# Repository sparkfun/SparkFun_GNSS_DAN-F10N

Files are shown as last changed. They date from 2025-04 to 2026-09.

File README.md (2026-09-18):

SparkFun Dualband L1/L5 GNSS Breakout - DAN-F10N
========================================

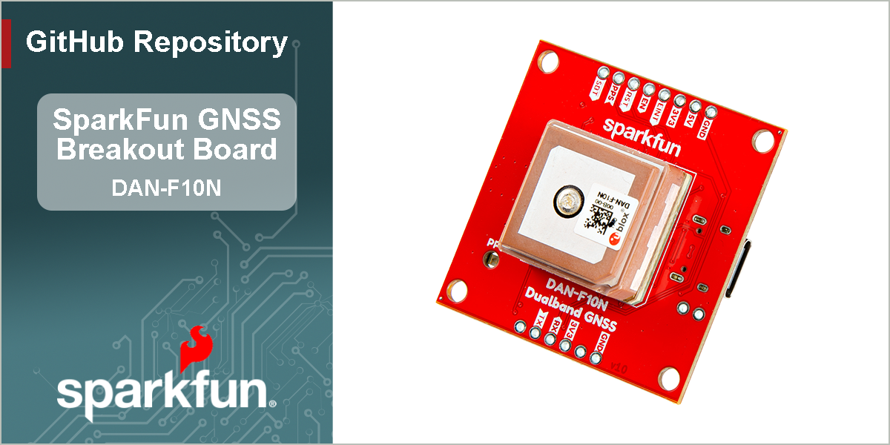
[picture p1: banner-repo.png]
SparkFun Dualband L1/L5 GNSS Breakout - DAN-F10N


[*SparkFun Dualband L1/L5 GNSS Breakout - DAN-F10N (GPS-28435)*](https://www.sparkfun.com/sparkfun-dualband-l1-l5-gnss-breakout-dan-f10n.html)

The SparkFun DAN-F10N Dualband GNSS Breakout is built around the powerful u-blox F10 engine, offering simultaneous reception of L1 and L5 frequency bands. This board leverages u-blox's advanced multipath mitigation technology to isolate the strongest signals, delivering reliable, meter-level position accuracy even in dense urban canyons. To ensure signal integrity, the module incorporates a robust SAW-LNA-SAW RF front-end with an additional notch filter (LTE B13), providing excellent rejection of interference from nearby cellular modems.

The SparkFun Dualband L1/L5 GNSS Breakout - DAN-F10N features u-blox's dual-band GNSS technology for the L1/L5 frequency bands. Their proprietary dual-band multipath mitigation technology enables the u-blox F10 GNSS engine to isolate the best signals from the L1 and L5 bands; delivering a solid meter-level position accuracy in challenging urban environments. Additionally, the DAN-F10N module's robust SAW-LNA-SAW RF architecture with an additional notch filter (LTE B13) on the L1 RF path ensures the best possible out-of-band interference mitigation from nearby cellular modems.

The DAN-F10N GNSS module on this board comes with a 20 x 20 x 8 mm, integrated, Right Hand Circular Polarized (RHCP), L1/L5 dual-band patch antenna that offers the best compromise between size and performance. The patch antenna's wide beamwidth provides flexibility in the device's orientation; while alternatively, the module also has an antenna switch function to give users the option to utilize an external dual-band antenna, further increasing its utility.

The DAN-F10N module is supported by the u-blox u-center 2 GNSS software for real-time performance analysis, receiver configuration, and data logging. The AssistNow Online, Offline, and Autonomous A-GNSS services can also be used with the module for faster satellite acquisition. Users can also interface with the GNSS module using NMEA 4.11 and UBX binary protocols.

> [!NOTE]
> The GPS `L5` signals are currently, considered as *"pre-operational"* and not utilized by default in navigation solutions. However, it is possible override the receiver's configuration to evaluate the GPS `L5` signals. Please refer to the integration manual for more details.
> 
> This is an operational limitation of the satellite/space segment and not an issue of the u-blox product.

Documentation
-------------

- **[Hookup Guide (mkdocs)](http://docs.sparkfun.com/SparkFun_GNSS_DAN-F10N/)** - A hookup guide for the SparkFun DAN-F10N Dualband L1/L5 GNSS breakout board hosted by GitHub pages.<br>
   
- [SparkFun u-blox GNSS v3 Arduino Library](https://github.com/sparkfun/SparkFun_u-blox_GNSS_v3) - An Arduino library for the u-blox GNSS module

Repository Contents
-------------------

- **[/docs](/docs/)** - Online documentation files
  - [/assets](/docs/assets/) - Assets files
    - [/3d_model](/docs/assets/3d_model/) - 3D models for the board
    - [/board_files](/docs/assets/board_files/) - Design files for the board
      - [KiCad Design Files](/docs/assets/board_files/kicad_files.zip) (.zip)
      - [Schematic](/docs/assets/board_files/schematic.pdf) (.pdf)
      - [Dimensions](/docs/assets/board_files/dimensions.pdf) (.pdf)
    - [/component_documentation](/docs/assets/component_documentation/) - Datasheets for hardware components
    - [/img/hookup_guide](/docs/assets/img/hookup_guide/) - Images for hookup guide documentation - Hookup guide images for the board
    - /Hardware - Hardware design files (.brd, .sch)
      - /Production - Production files

Product Variants
----------------

- [GPS-28435](https://www.sparkfun.com/sparkfun-dualband-l1-l5-gnss-breakout-dan-f10n.html) - Breakout Board
- [GPS-29061](https://www.sparkfun.com/sparkpnt-gnss-flex-module-dan-f10n.html) - SparkPNT GNSS Flex Module
- [GPS-29491](https://www.sparkfun.com/sparkfun-gnss-flex-phat-dan-f10n.html) - SparkFun GNSS Flex pHAT *(kit)*

Version History
---------------

- [v10](https://github.com/sparkfun/SparkFun_GNSS_DAN-F10N/releases/tag/v10) - Initial Release

License Information
-------------------

This product is ***open source***!

Please review the [`LICENSE.md`](./LICENSE.md) file for license information.

If you have any questions or concerns about licensing, please contact technical support on our [SparkFun forums](https://community.sparkfun.com/).

Distributed as-is; no warranty is given.

- Your friends at SparkFun.

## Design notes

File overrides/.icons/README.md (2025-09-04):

.icons directory
====================
This folder should contain branding logos for the product documentation

## General Images
- `sfe.svg` - SparkFun flame logo
- `kicad-primary.svg` - Full KiCad logo

## Directory
- `logo` - Other available logos

## SVG Optimizer
- [Remove meta data from svg](https://jakearchibald.github.io/svgomg/)

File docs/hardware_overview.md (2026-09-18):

## :material-folder-cog: Design Files

<!-- Import the component -->
<script type="module" src="https://ajax.googleapis.com/ajax/libs/model-viewer/3.5.0/model-viewer.min.js"></script>

<div class="grid cards desc" markdown>

-   :kicad-primary:{ .enlarge-logo } Design Files

	---

	- :fontawesome-solid-file-pdf: [Schematic](./assets/board_files/schematic.pdf)
	- :material-folder-zip: [KiCad Files](./assets/board_files/kicad_files.zip)
	- :material-rotate-3d: [STEP File](./assets/3d_model/cad_model.step)
	- :fontawesome-solid-file-pdf: [Board Dimensions](./assets/board_files/dimensions.pdf):
		- 2.50" x 2.00" (635mm x 508mm)

-   <!-- Boxes in tabs -->

	=== "3D Model"
		<article style="text-align: center;" markdown>
		<model-viewer src="../assets/3d_model/web_model.glb" camera-controls poster="../assets/3d_model/poster.png" tone-mapping="neutral" shadow-intensity="2" shadow-softness="0.2" camera-orbit="0deg 75deg 0.103m" field-of-view="25.11deg" style="width: 100%; height: 450px;">
		</model-viewer>

		[Download the `*.step` File](./assets/3d_model/cad_model.step "Click download"){ .md-button .md-button--primary width="250px" }

		</article>

		???+ tip "Manipulate 3D Model"
			<article style="text-align: center;" markdown>

			| Controls       | Mouse                    | Touchscreen    |
			| :------------- | :----------------------: | :------------: |
			| Zoom           | Scroll Wheel             | 2-Finger Pinch |
			| Rotate         | ++"Left-Click"++ & Drag  | 1-Finger Drag  |
			| Move/Translate | ++"Right-Click"++ & Drag | 2-Finger Drag  |

			</article>

	=== "Dimensions"
		<article style="text-align: center;" markdown>
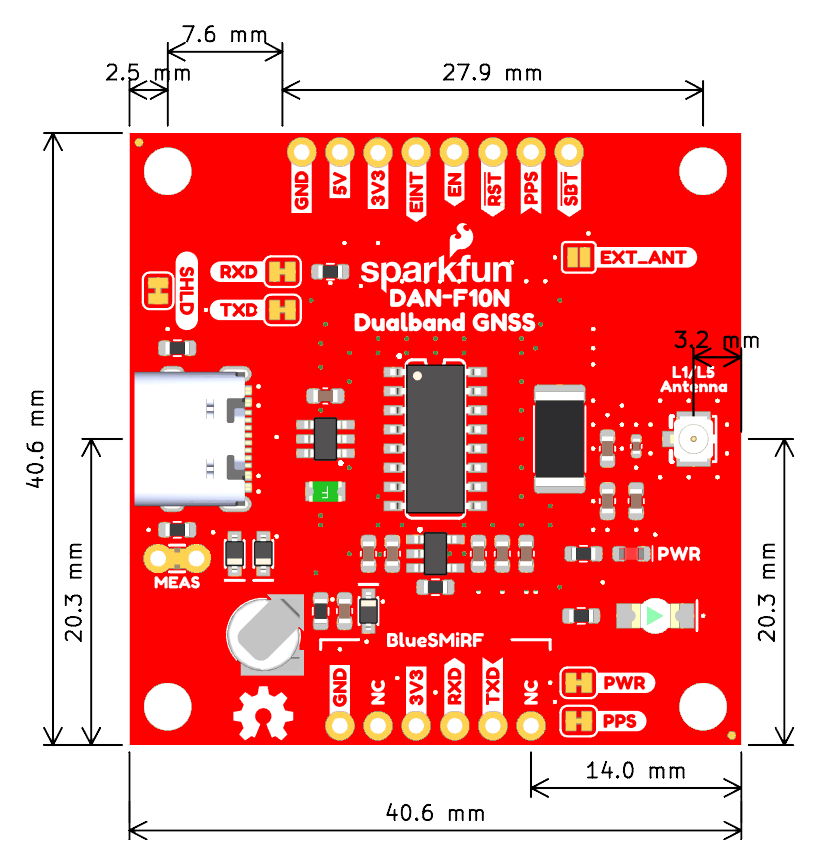
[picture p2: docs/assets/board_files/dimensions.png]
Board Dimensions
		
		<figcaption markdown>Dimensions of the DAN-F10N GNSS breakout board.</figcaption>
		</article>

		???+ tip "Need more measurements?"
			For more information about the board's dimensions, users can download the [KiCad files](./assets/board_files/kicad_files.zip) for this board. These files can be opened in KiCad and additional measurements can be made with the measuring tool.

			!!! info ":octicons-download-16:{ .heart } KiCad - Free Download!"
				KiCad is free, open-source [CAD]("computer-aided design") program for electronics. Click on the button below to download their software. *(\*Users can find out more information about KiCad from their [website](https://www.kicad.org/).)*

				<article style="text-align: center;" markdown>
				[Download :kicad-primary:{ .enlarge-logo }](https://www.kicad.org/download/ "Go to downloads page"){ .md-button .md-button--primary width="250px" }
				</article>

			???+ info ":straight_ruler: Measuring Tool"
				This video demonstrates how to utilize the dimensions tool in KiCad, to include additional measurements:

				<article class="video-500px" style="text-align: center; margin: auto;" markdown>
				<iframe src="https://www.youtube.com/embed/-eXuD8pkCYw" title="KiCad Dimension Tool" frameborder="0" allow="accelerometer; autoplay; clipboard-write; encrypted-media; gyroscope; picture-in-picture" allowfullscreen></iframe>
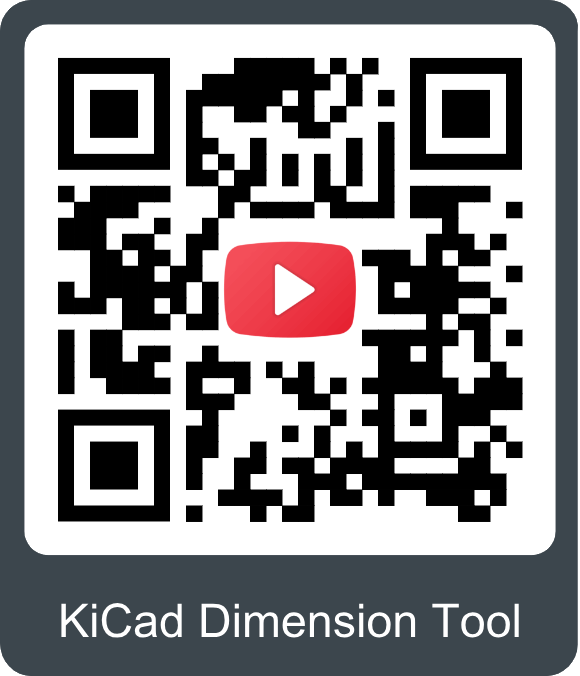
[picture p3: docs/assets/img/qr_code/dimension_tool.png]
QR code to play video
				
				</article>

</div>

## Board Layout
The SparkFun Dualband L1/L5 GNSS Breakout - DAN-F10N features the following:

<div class="grid" markdown>

<div markdown>

<figure markdown>
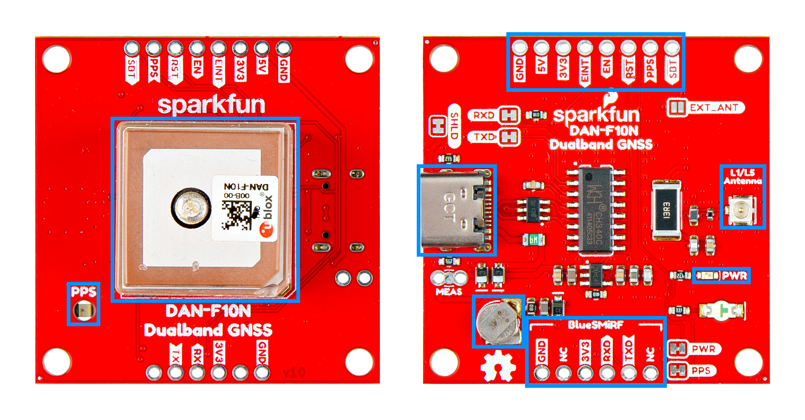
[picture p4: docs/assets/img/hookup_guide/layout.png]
Layout

<figcaption markdown>Layout of the major components on the breakout board.</figcaption>
</figure>

</div>

<div markdown>

1. **USB-C Connector**
:   The primary inteface for powering and interacting with the board
1. **DAN-F10N GNSS Module**
:   The u-blox DAN-F10N GNSS module
1. **Headers**
:   Exposes pins to power the board and breaks out the pins of the DAN-F10N GNSS module
1. **Status LEDs**
:   LED status indicators for the DAN-F10N GNSS module
1. **`L1/L5 Antenna` U.FL Connector**
:   An optional input for an external GNSS antenna
1. **Backup Battery**
:   Backup power to maintain ephemeris data on the DAN-F10N GNSS module for warm starts

</div>

</div>

## Power
The simplest method to power the board is through the USB-C connector. However, the DAN-F10N Dualband L1/L5 GNSS breakout board only requires **3.3V**, which can be supplied though the [PTH](https://en.wikipedia.org/wiki/Through-hole_technology "Plated Through Holes") pins.

<figure markdown>
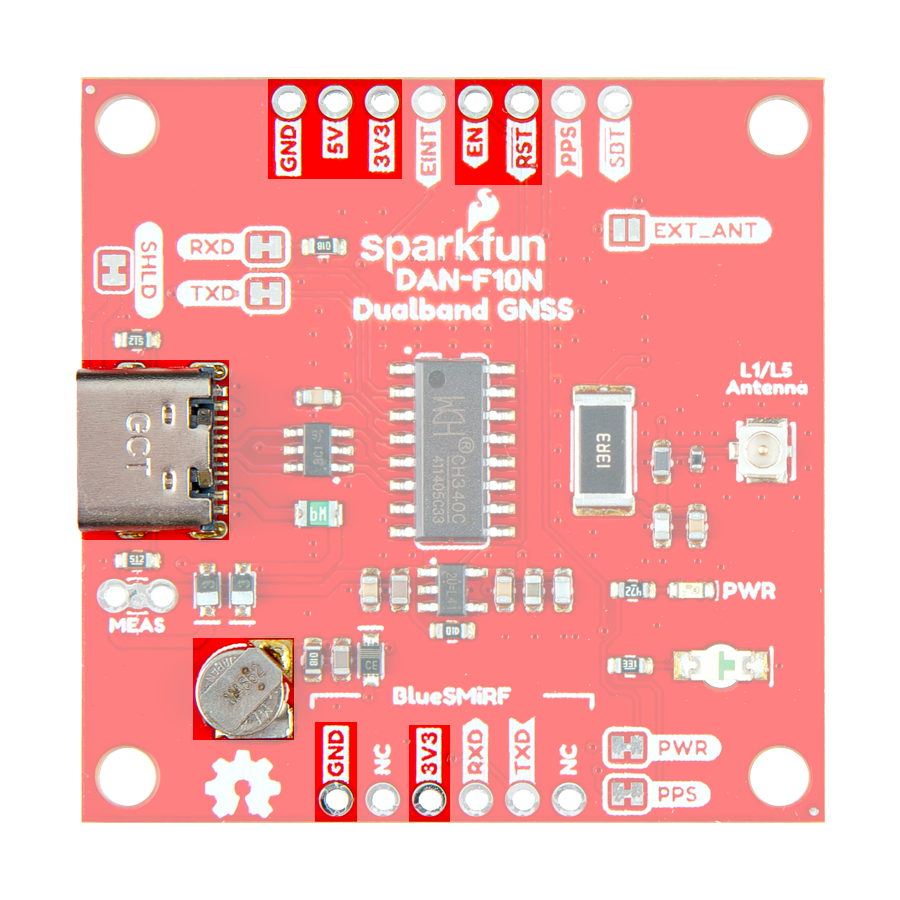
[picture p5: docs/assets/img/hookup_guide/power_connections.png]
Power connections

<figcaption markdown>DAN-F10N Dualband L1/L5 GNSS breakout board's power connections.</figcaption>
</figure>

Below, is a general summary of the power circuitry on the board; most are broken out as [PTH](https://en.wikipedia.org/wiki/Through-hole_technology "Plated Through Holes") pins:

<div class="annotate" markdown>

- **`5V`** - The voltage from the USB-C connector, usually **5V**.
	- Input Voltage Range: 1.2 - 5.5V (1)
	- Power source for the entire board
		- Powers the 3.3V voltage regulator (RT9080), which can source up to 600mA
		- When enabled, it can also power the [BlueSMiRF header](#bluesmirf-header)
- **`3V3`** - Provides a regulated 3.3V from the [RT9080](./assets/component_documentation/RT9080.pdf), using the power supplied from the `5V` pin or USB-C connector.
	- Used to power the DAN-F10N module, power LED, and backup battery
	- Controlled by the `EN` pin, which is enabled by default
- **`EN`** - Controls the 3.3V voltage regulator [RT9080](./assets/component_documentation/RT9080.pdf), enabling the voltage output *(active `HIGH`)*
- **`RST`** - Used to reset the DAN-F10N GNSS module
	- Connected to the [`RESET_N` pin](#pio-pins) of the DAN-F10N module, an input-only pin with an internal pull-up resistor (2)
	- Driving the pin `LOW` for at least 1ms triggers a cold-start reset, clearing the `BBR` content *(receiver configuration, real-time clock (RTC), and GNSS orbit data)*
- **`GND`** - The common ground or the 0V reference for the voltage supplies.
- **Backup Battery** - Provides backup power to the DAN-F10N GNSS module to maintain ephemeris data for warm starts

</div>

1. While the [RT9080](./assets/component_documentation/RT9080.pdf) LDO regulator has an input voltage range of 1.2 - 5.5V, a minimum supply voltage of **3.5V** is recommended for a 3.3V output.

1. No capacitors should be placed between `RESET_N` to GND, otherwise it could trigger a reset on every startup.

!!! tip "JST Connector"
	The `3V3` pin of the [BlueSMiRF header](#bluesmirf-header) is designed to operate as a voltage output. However, an input voltage can be supplied through the pin, but users should be mindful of any voltage contention issues.

!!! info
	For more details, users can reference the [schematic](./assets/board_files/schematic.pdf) and the datasheets of the individual components on the board.

### Power Modes
The DAN-F10N GNSS module supports three different operation modes:

- ***Continuous Mode***

:   In this mode, the module uses dedicated signal processing engines optimized for signal acquisition and tracking.

	- The acquisition engine actively searches and acquires signals, during cold starts or when insufficient signals are available during navigation.
	- The tracking engine continuously tracks signals, downloads all the almanac data, and acquires new signals as they become available during navigation.
	
	The tracking engine consumes less power than the acquisition engine. Therefore, the module's current consumption is lower when a valid position is obtained quickly after startup, the entire almanac has been downloaded, and the ephemeris for available satellites are valid.

- *Backup Modes*

:   The DAN-F10N module supports two backup modes. The backup modes are inactive states with reduced power consumption, where the receiver maintains time, information, and navigation data to speed up signal acquisitions upon restart.

	- **Hardware backup mode**

	:   The hardware backup mode requires `V_BCKP` power to be supplied. It allows the module to enter a backup state and maintain the backup domain (`BBR` and `RTC`), after the main power has been switched off.

	- **Software standby mode**

	:   Software standby mode is entered using the `UBX-RXM-PMREQ` message. This mode will clear the RAM memory; to maintain the receiver configuration, it should be stored on `BBR` or flash layers. The software standby mode can be set for a specific duration, or until the receiver is woken up by a signal from the UART `RX` and/or `EXTINT` pins, as defined in `UBX-RXM-PMREQ` message. A system reset with the `RESET_N` signal also terminates the software standby mode, clears the `BBR` content and restarts the receiver.

### Power Consumption
The power consumption of the DAN-F10N module depends on the GNSS signals enabled and if the module is acquiring or tacking those signals. The table below, lists the average current consumption with a supply voltage of 3.3V.

<div class="grid cards" markdown>

<article style="text-align: center;" markdown>

| GNSS Signals | Acquisition | Tracking |
| :--- | :---: | :---: |
| GPS+GAL+BDS  | 26mA | 21mA |
| GPS+BDS | 26mA | 20mA |
| GPS+GAL | 22mA | 19mA |
| GPS+NavIC | 21mA | 18mA |
| GPS | 20mA | 18mA |
| BDS | 24mA | 19mA |

</article>

<div markdown>

!!! tip
	At startup, the inrush current can reach up to 100 mA at startup. Make sure the primary power source can sustain the required current consumption.

!!! info "Backup Modes"
	The current consumption for the backup modes:

	- Hardware backup Mode: 31µA
	- Software standby Mode: 49µA

!!! info
	For more information, please refer to the [DAN-F10N Datasheet](./assets/component_documentation/DAN-F10N_DataSheet_UBXDOC-963802114-13074.pdf).

</div>

</div>

## DAN-F10N GNSS Receiver
The centerpiece of the DAN-F10N Dualband L1/L5 GNSS breakout board, is the [DAN-F10N module](./assets/component_documentation/DAN-F10N_DataSheet_UBXDOC-963802114-13074.pdf) from [u-blox](https://www.u-blox.com/en). Their proprietary dual-band multipath mitigation technology enables the u-blox F10 GNSS engine to isolate the best signals from the L1 and L5 bands; delivering a solid meter-level position accuracy in challenging urban environments. Additionally, the DAN-F10N module's robust SAW-LNA-SAW RF architecture with an additional notch filter on the L1 RF path ensures the best possible out-of-band interference mitigation from nearby cellular modems.

The DAN-F10N GNSS module comes with a 20 x 20 x 8 mm, integrated, Right Hand Circular Polarized (RHCP), L1/L5 dual-band patch antenna that offers the best compromise between size and performance. The patch antenna's wide beamwidth provides flexibility in the device's orientation; while alternatively, the module also has an antenna switch function to give users the option to utilize an external dual-band antenna, further increasing its utility.

<div class="grid cards" markdown>

<div markdown>

<article class="video-500px" style="text-align: center; margin: auto;" markdown>
<iframe src="https://www.youtube.com/embed/7_Pxe2rVFIQ" title="u-blox F10 GNSS platform for meter-level accuracy in urban environments" frameborder="0" allow="accelerometer; autoplay; clipboard-write; encrypted-media; gyroscope; picture-in-picture" allowfullscreen></iframe>
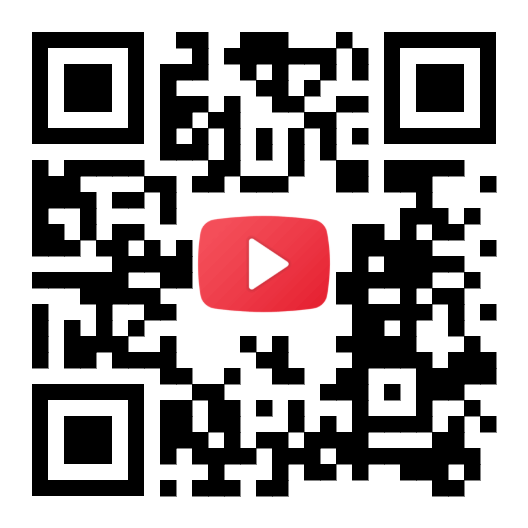
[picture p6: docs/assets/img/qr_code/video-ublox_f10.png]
QR code

</article>

</div>

-   <figure markdown>
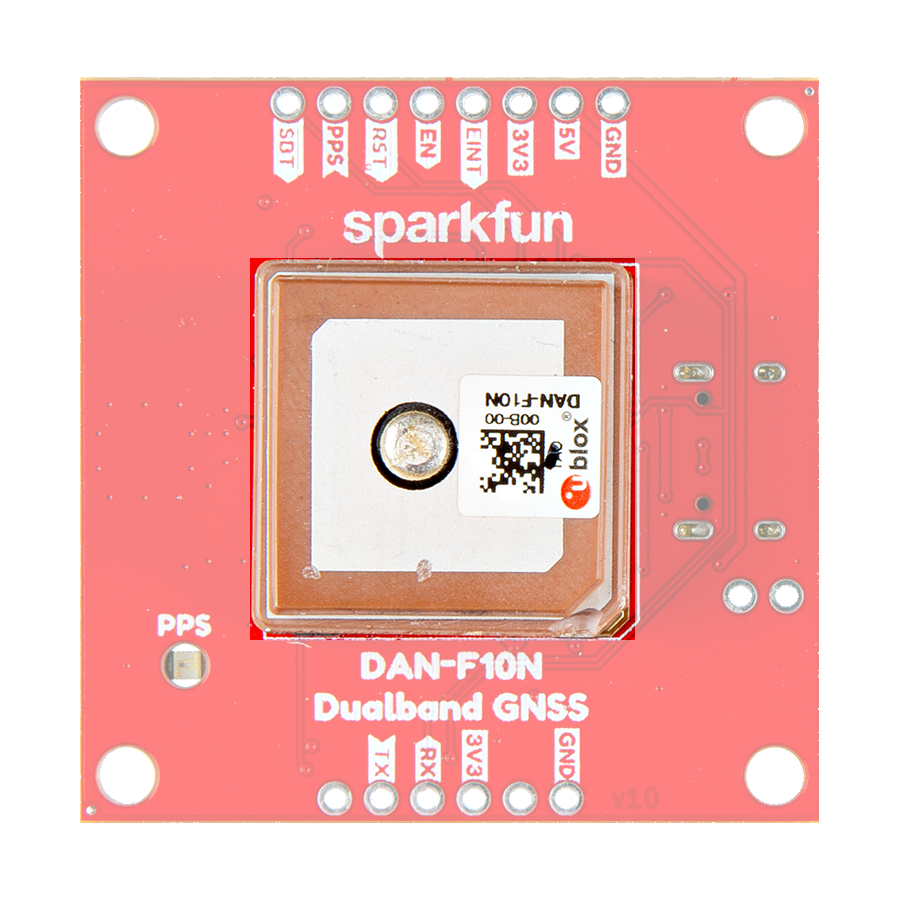
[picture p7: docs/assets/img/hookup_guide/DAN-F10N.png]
DAN-F10N module
	
	<figcaption markdown>The DAN-F10N module on the breakout board.</figcaption>
	</figure>

</div>

<div class="grid" markdown>

<div markdown>

**Features:**

- Operating Voltage: **2.7 - 3.6V**
- Operating Temperature: -40 - 85&deg;C
- GNSS Support
	- GPS: L1 C/A, L5
	- QZSS: L1C/A, L1S, L1Sb, L5
	- GAL: E1B/C, E5a
	- BDS: B1C, B2a
	- NavIC: L5
	- SBAS: L1C/A
	- BDSBAS: B1C
- Sensitivity
	- Tracking & Nav: –164dBm
	- Reacquisition: –156dBm
	- Cold start: –145dBm
	- Hot start: –156dBm

</div>

<div markdown>

<br>

- Update Rate: Up to 10Hz
- Time to Fix
	- Cold Start: < 28s
	- Aided Start: < 2s
	- Hot Start: 2s
- Position Accuracy
	- 1.0 m (with SBAS)
	- 1.5 m (without SBAS)
- Interfaces
	- 1x Serial interface
		- Raw data output: Code phase data
		- Protocols: NMEA 4.11, UBX binary
	- 2x Digital I/O
		- Timepulse Configurable: 0.25 - 10MHz
		- `EXTINT` input for Wakeup

</div>

</div>

### Frequency Bands
The DAN-F10N GNSS module is a dual-band, multi-constellation GNSS receiver. Below, are the frequency bands provided by all the global navigation satellite systems and the ones supported by the DAN-F10N module.

<div class="grid cards desc" markdown>

<article style="text-align: center;" markdown>

| Constellation | Frequency Bands |
| :---: | :--- |
| GPS | L1 C/A, L5 |
| QZSS | L1C/A, L1S, L1Sb, L5 |
| GAL | E1B/C, E5a |
| BDS | B1C, B2a |
| NavIC | L5 |
| SBAS | L1C/A |
| BDSBAS | B1C |

*The frequency bands supported by the DAN-F10N GNSS receiver.*
</article>

<div markdown>

<figure markdown>
GNSS frequency bands (https://www.tallysman.com/app/uploads/2021/07/Tallysman-GNSS-Frequencies-v8.0_Chart-1-1024x425.png "Click to enlarge")
<figcaption markdown>Frequency bands of the global navigation satellite systems. (Source: [Tallysman](https://www.tallysman.com/gnss-constellations-radio-frequencies-and-signals/))</figcaption>
</figure>

</div>

</div>

??? info "What are Frequency Bands?"
	A [frequency band](https://en.wikipedia.org/wiki/Frequency_band) is a section of the [electromagnetic spectrum](https://en.wikipedia.org/wiki/Electromagnetic_spectrum), usually denoted by the range of its upper and lower limits. In the [radio spectrum](https://en.wikipedia.org/wiki/Radio_spectrum), these frequency bands are usually regulated by region, often through a government entity. This regulation prevents the interference of RF communication; and often includes major penalties for any interference with critical infrastructure systems and emergency services.

	<figure markdown>
	GNSS frequency bands (https://gssc.esa.int/navipedia/images/c/cf/GNSS_All_Signals.png "Click to enlarge")
	<figcaption markdown>Frequency bands of the global navigation satellite systems. (Source: [ESA](https://gssc.esa.int/navipedia/index.php?title=File:GNSS_All_Signals.png "European Space Agency"))</figcaption>
	</figure>

	However, if the various GNSS constellations share similar frequency bands, then how do they avoid interfering with one another? Without going too far into detail, the image above illustrates the frequency bands of each system with a few characteristics specific to their signals. Wit these characteristics in mind, along with other factors, the chart can help users to visualize how multiple GNSS constellations might co-exist with each other.

	For more information, users may find these articles of interest:

	- [GNSS signal](https://gssc.esa.int/navipedia/index.php/GNSS_signal)
	- [GPS Signal Plan](https://gssc.esa.int/navipedia/index.php?title=GPS_Signal_Plan)
	- [GLONASS Signal Plan](https://gssc.esa.int/navipedia/index.php?title=GLONASS_Signal_Plan)
	- [GALILEO Signal Plan](https://gssc.esa.int/navipedia/index.php?title=GALILEO_Signal_Plan)

## Peripherals and I/O Pins
The DAN-F10N module has twelve I/O pins, of which five are programmable. Most of these are broken out as [PTH](https://en.wikipedia.org/wiki/Through-hole_technology "Plated Through Holes") pins on the DAN-F10N Dualband L1/L5 GNSS breakout board; whereas, others are broken out to their specific interface *(i.e. USB connector, jumper, U.FL connector, etc.)*. Additionally, some of the I/O connections are broken out with multiple components or interfaces.

<div class="grid cards" markdown>

<div markdown>

<figure markdown>
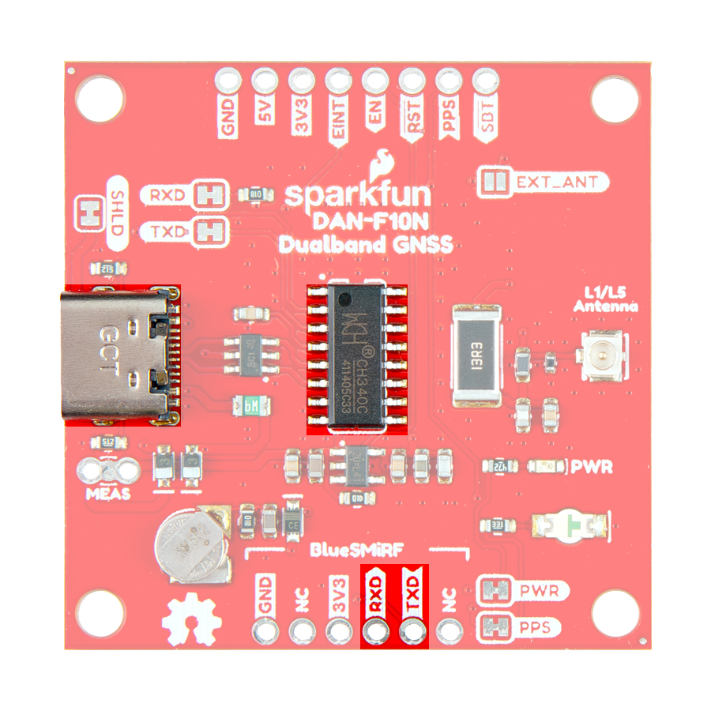
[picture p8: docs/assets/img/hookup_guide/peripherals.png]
UART Interface

<figcaption markdown>The UART interfaces on the DAN-F10N GNSS breakout board.</figcaption>
</figure>

</div>

<div markdown>

<figure markdown>
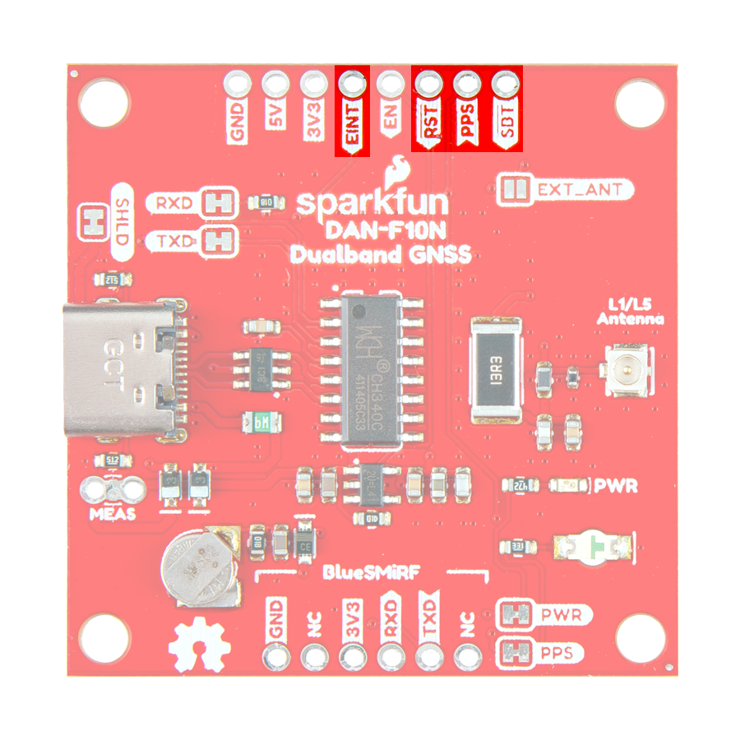
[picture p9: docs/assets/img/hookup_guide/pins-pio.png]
I/O pins

<figcaption markdown>The I/O pins on the DAN-F10N GNSS breakout board.</figcaption>
</figure>

</div>

<div markdown>

<article class="annotate" markdown>
**Interfaces:**

- 1x UART
- ~~1x LNA enable pin~~ (1)
- 1x External interrupt
- 1x PPS output signal
- 1x Safe boot pin
- 1x Reset pin

</article>

1. Not available on the DAN-F10N Dualband L1/L5 GNSS breakout board.

</div>

</div>

=== "UART Interface"

	<div class="grid" markdown>

	<div markdown>

	<figure markdown>
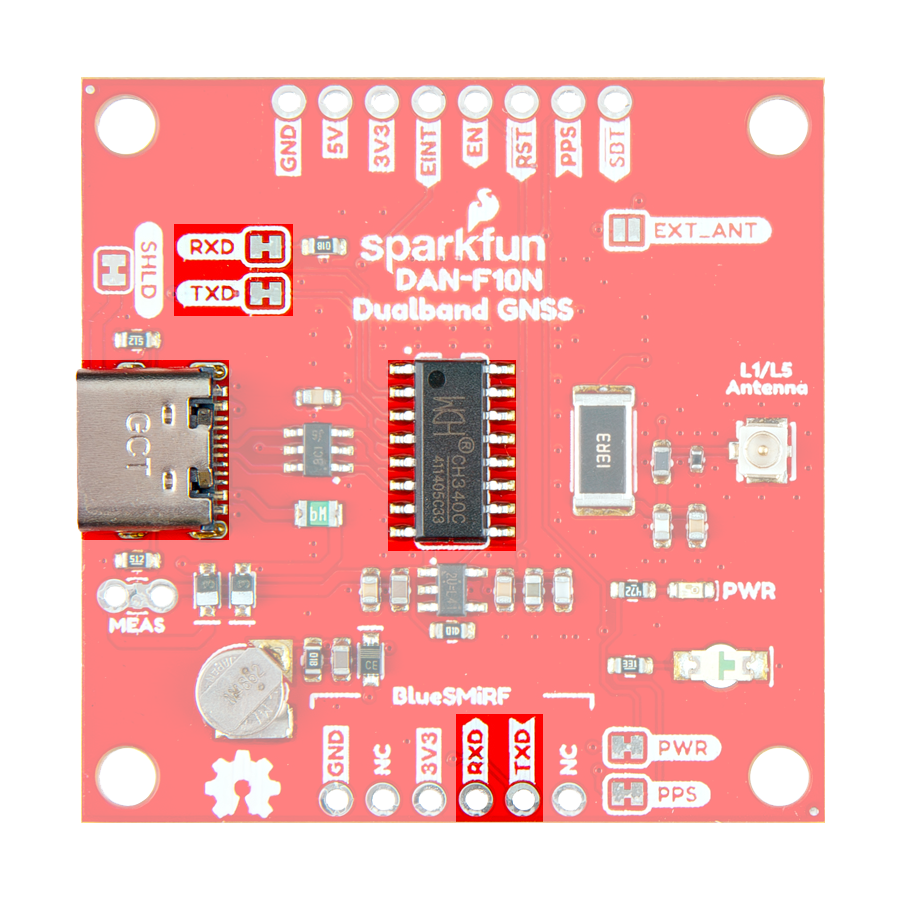
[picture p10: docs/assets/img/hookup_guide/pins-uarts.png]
UART I/O pins
	
	<figcaption markdown>The `COM` pins on the DAN-F10N GNSS breakout board.</figcaption>
	</figure>

	</div>

	<div markdown>

	The DAN-F10N has a single UART interface that can be accessed either through the [PTH](https://en.wikipedia.org/wiki/Through-hole_technology "Plated Through Holes") pins or the USB-C connector, with the help of the CH340 USB-to-serial converter. The operation of these connections is configured with the [`RX` and `TX` jumpers](#jumpers).

	!!! info "Supported Protocols"
		The UART interface supports the following protocols:

		- Input messages: NMEA and UBX
		- Output messages: NMEA (GGA, GLL, GSA, GSV, RMC, VTG, and TXT)

	!!! info "Configuration Settings"
		The UART interface can be configured with the `CFG-UART1-*` messages, but will initially have the following settings:

		- Baudrate: 9600 to 921600bps *(Default: 38400bps)*
		- Data Bits: 8
		- Parity: No
		- Stop Bits: 1
		- Flow Control: None

	</div>

	</div>

=== "PIO Pins"

	<div class="grid" markdown>

	<div markdown>

	<figure markdown>
	General purpose I/O pins
	<figcaption markdown>The `GPx` pins on the DAN-F10N GNSS breakout board.</figcaption>
	</figure>

	</div>

	<div markdown>

	The DAN-F10N module features five programmable I/O pins, but the LNA enable pin is not broken out on this board. All the inputs have internal pull-up resistors in normal operation and can be left open if unused.

	- **`EXTINT`**
	:   DAN-F10N supports external interrupts through its `EXTINT` pin. This is useful for waking the module up from its standby mode or for timing applications.

	- **`SBT`** *(Reserved for future use)*
	:   The `SAFEBOOT_N` pin is for updates and reconfiguration. The DAN-F10N module will enter safeboot mode, if this pin is pulled `LOW` at starup.

	- **`PPS`**
	:   The [`PPS` pin](#pps-output) is connected to the `TIMEPULSE` pin of the DAN-F10N and the [`PPS` LED](#status-leds). The period, length, and polarity (rising or falling edge) of the `TIMEPULSE` signal can be configured with the `CFG-TP-*` messages.

			!!! info
				The `SBT` (`SAFEBOOT_N`) and `PPS` (`TIMEPULSE`) pins are internally connected in the DAN-F10N module, by a 1 k&ohm; series resistor. Make sure these pins have no load that could pull them low at startup; otherwise, the receiver will enter its safeboot mode.

	- **`RST`**
	:	The `RST`pin is connected to the `RESET_N` pin of the DAN-F10N module. Driving the pin `LOW` for at least 1ms triggers a cold-start reset, clearing the `BBR` content *(receiver configuration, real-time clock (RTC), and GNSS orbit data)*.

			!!! info
				Capacitors should not be placed between `RST` and `GND`; otherwise, it could trigger a reset on startup.

	</div>

	</div>

=== "PPS Output"

	<div class="grid" markdown>

	<div markdown>

	<figure markdown>
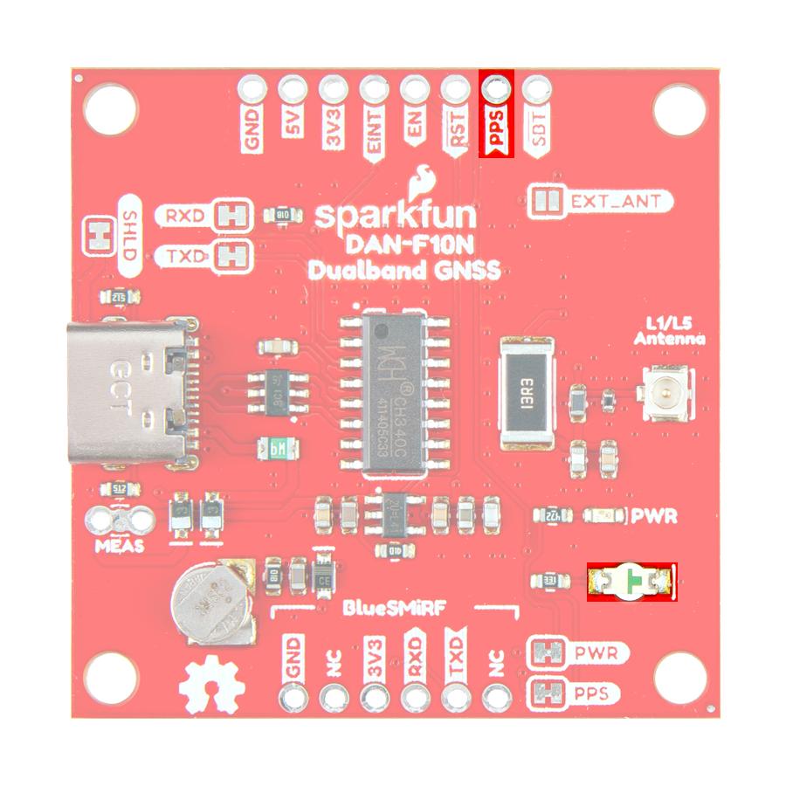
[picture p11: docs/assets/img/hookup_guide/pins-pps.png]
PPS signal I/O pin
	
	<figcaption markdown>The `PPS` output signal on the DAN-F10N GNSS breakout board.</figcaption>
	</figure>

	</div>

	<div markdown>

	The [`PPS`](https://en.wikipedia.org/wiki/Pulse-per-second_signal "Pulse Per Second") pin is connected to the module's time pulse (`TIMEPULSE`) signal and the [`PPS` LED](#status-leds), as a visual indicator. The period, length, and polarity (rising or falling edge) of the `TIMEPULSE` signal can be configured with the `CFG-TP-*` messages.

	!!! tip "Disable LED"
		There is a [jumper](#jumpers) attached to the `PPS` LED. For low power applications, users can cut the jumper to disable the `PPS` LED.

	!!! info
		The module's `SAFEBOOT_N` (`SBT`) pin is internally connected to its `TIMEPULSE` (`PPS`) pin through a 1 k&ohm; series resistor. Make sure these pins have no load that could pull them low at startup; otherwise, the receiver will enter its safeboot mode.

	</div>

	</div>

### USB-C Connector
A USB connector is provided to power the board and interface with the DAN-F10N GNSS receiver through a CH340 USB-to-serial converter. For most users, it will be the primary method for communicating with the DAN-F10N module.

<figure markdown>
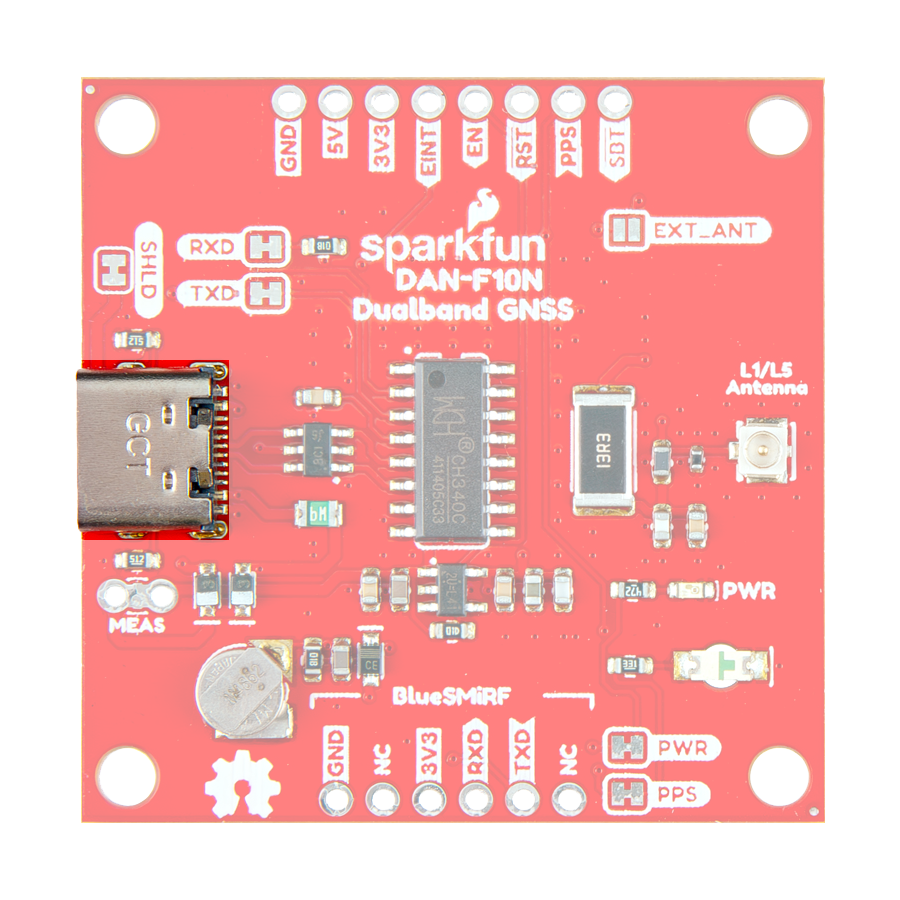
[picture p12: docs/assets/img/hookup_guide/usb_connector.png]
USB-C Connector

<figcaption markdown>USB-C connector on the DAN-F10N GNSS breakout board.</figcaption>
</figure>

!!! info
	Users will need to [install the USB driver](software_overview.md#usb-driver) for the CH340 USB-to-serial converter, before they can interact with the DAN-F10N GNNS module.

### U.FL Connector
The `L1/L5 Antenna` U.FL connector provides an optional, input for a external GNSS antenna. Users will need to modify the [`EXT_ANT` jumper](#jumpers), to trigger the RF switch to change from the integrated patch antenna to the external antenna connection.

<figure markdown>
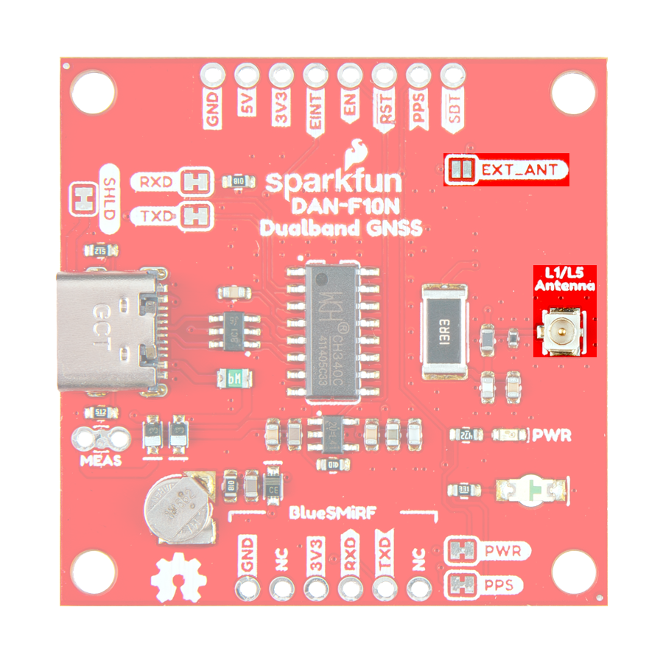
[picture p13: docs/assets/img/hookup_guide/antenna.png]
GNSS antenna input

<figcaption markdown>The U.FL connector to attach an external GNSS antenna to the DAN-F10N GNSS breakout board.</figcaption>
</figure>

!!! tip
	For the best performance, we recommend users choose a compatible L1/L5 GNSS antenna and utilize a low-loss cable. Also, don't forget that GNSS signals are fairly weak and can't penetrate buildings or dense vegetation. The GNSS antenna should have an unobstructed view of the sky.

### BlueSMiRF Header
The DAN-F10N has a single [UART interface](#uart-interface) that can be accessed either through the BlueSMiRF header pins or the USB-C connector. The BlueSMiRF header can be used to connect the DAN-F10N GNSS module to external devices, such as a microcontroller or [BlueSMiRF v2](https://www.sparkfun.com/sparkfun-bluesmirf-v2.html), Bluetooth^&reg;^ serial link.

<div class="grid" markdown>

<figure markdown>
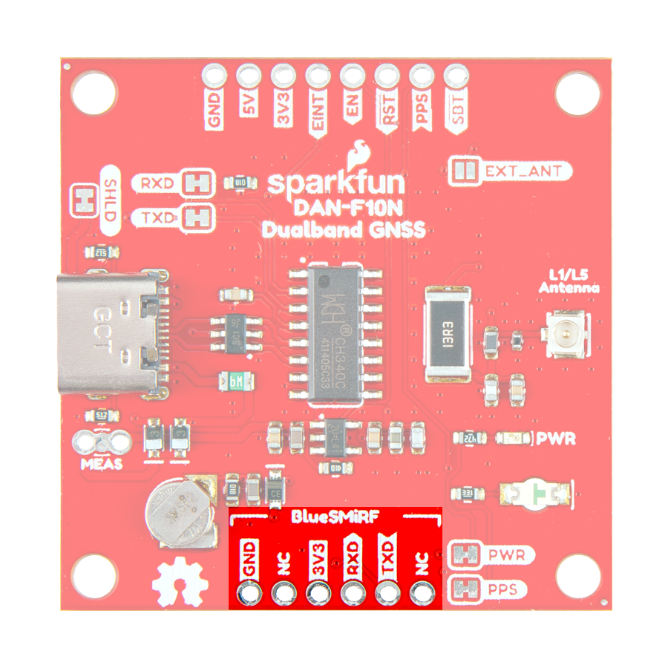
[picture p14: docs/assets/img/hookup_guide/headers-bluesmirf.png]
JST Connector

<figcaption markdown>The BlueSMiRF header pins on the DAN-F10N GNSS breakout board.</figcaption>
</figure>

<div markdown>

!!! info "Supported Protocols"
	The UART interface supports the following protocols:

	- Input messages: NMEA and UBX
	- Output messages: NMEA (GGA, GLL, GSA, GSV, RMC, VTG, and TXT)

!!! info "Configuration Settings"
	The UART interface can be configured with the `CFG-UART1-*` messages, but will initially have the following settings:

	- Baudrate: 9600 to 921600bps *(Default: 38400bps)*
	- Data Bits: 8
	- Parity: No
	- Stop Bits: 1
	- Flow Control: None

</div>

</div>

!!! warning "Bus Contention"
	To avoid [bus contention](https://en.wikipedia.org/wiki/Bus_contention) issues between the USB-C connection and the external device, users may want to use the [`RXD` and `TXD` jumpers](#jumpers) to disconnect the CH340 USB-to-serial converter from the UART interface of the DAN-F10N GNSS module.

!!! tip "Pin Connections"
	When connecting the DAN-F10N Dualband L1/L5 GNSS breakout board to another device, users need to be aware of the pin connections and voltage ranges of the products. Below, is a table of the pin connections for the BlueSMiRF header pins on the DAN-F10N GNSS breakout board.

	<article style="text-align: center;" markdown>

	<table border="1" markdown>
	<tr markdown>
	<th style="vertical-align:middle;">Pin Number</th>
	<td align="center" markdown>
		**1**<br>
		*(Left Side)*
	</td>
	<td align="center" markdown>**2**</td>
	<td align="center" markdown>**3**</td>
	<td align="center" markdown>**4**</td>
	<td align="center" markdown>**5**</td>
	<td align="center" markdown>
		**6**<br>
		*(Right)*
	</td>
	</tr>
	<tr markdown>
	<th style="vertical-align:middle;">Label</th>
	<td align="center" markdown>`NC`</td>
	<td align="center" markdown>`TXD`</td>
	<td align="center" markdown>`RXD`</td>
	<td align="center" markdown>`3V3`</td>
	<td align="center" markdown>`NC`</td>
	<td align="center" markdown>`GND`</td>
	</tr>
	<tr markdown>
	<th style="vertical-align:middle;">Function</th>
	<td align="center" markdown></td>
	<td align="center" markdown>UART - Transmit</td>
	<td align="center" markdown>UART - Receive</td>
	<td align="center" markdown>Output Voltage: **3.3V**</td>
	<td align="center" markdown></td>
	<td align="center" markdown>Ground</td>
	</tr>
	</table>

	</article>

## Status LEDs

<div class="grid" markdown>

<figure markdown>
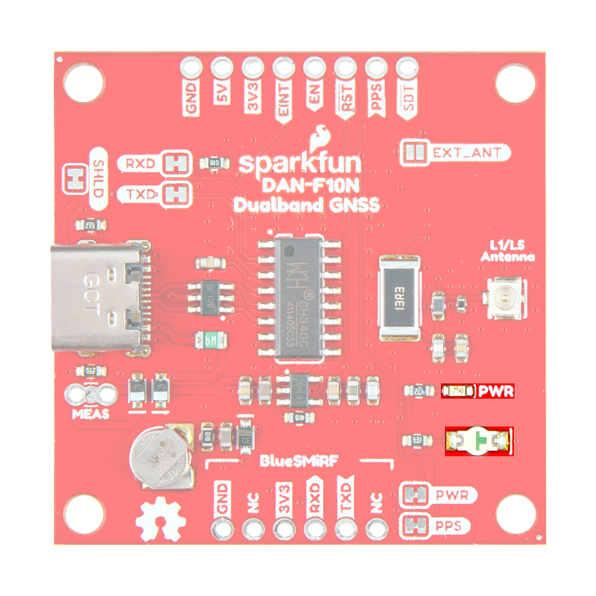
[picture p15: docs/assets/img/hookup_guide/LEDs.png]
Status LEDs

<figcaption markdown>The status indicator LEDs on the DAN-F10N Dualband L1/L5 GNSS breakout board.</figcaption>
</figure>

<div markdown>

There are two status LEDs on the DAN-F10N Dualband L1/L5 GNSS breakout board:

- `PWR` - Power *(Red)*
	- Turns on once 3.3V power is supplied to the board
- `PPS` - Pulse-Per-Second *(Green)*
	- Indicates when there is a time pulse signal *(see the **[PPS Output](#pps-output)** section)*

!!! info
	For low power applications, the LEDs can be disabled to conserve energy. *See the [**Jumpers** section](#jumpers).*

</div>

</div>

## Jumpers

??? note "Never modified a jumper before?"
	Check out our <a href="https://learn.sparkfun.com/tutorials/664">Jumper Pads and PCB Traces tutorial</a> for a quick introduction!

	<div class="grid cards" markdown align="center">

	-   <a href="https://learn.sparkfun.com/tutorials/664">
		<figure markdown>
		Tutorial thumbnail
		</figure>

		---

		**How to Work with Jumper Pads and PCB Traces**</a>

	</div>

There are seven jumpers on the back of the board that can be used to easily modify the hardware connections on the board.

<figure markdown>
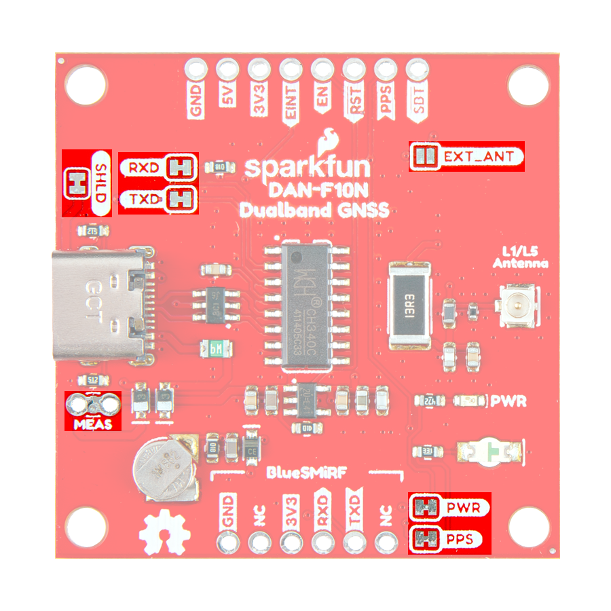
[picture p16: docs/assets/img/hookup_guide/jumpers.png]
Jumpers

<figcaption markdown>The jumpers on the bottom of the DAN-F10N Dualband L1/L5 GNSS breakout board.</figcaption>
</figure>

LED Jumpers
:   Two of the jumpers control power to the status LEDs on the board.

	!!! info
		By default, all the jumpers are connected, to power the status LEDs. For low power applications, users can cut the jumpers to disconnect power from each of the LEDs.

	- **`PWR`** - This jumper can be cut to remove power from the red, power LED.
	- **`PPS`** - This jumper can be cut to remove power from the green, `PPS` LED that is provided by the [`PPS` signal](#pps-output).

UART Jumpers
:   Two of the jumpers control the `RX` and `TX` signals on the board.

	!!! tip
		A 1k&ohm; resistor is placed on the

	- **`RXD`** - This jumper can be cut to disconnect the `RX` signal of the DAN-F10N module from the CH340 USB-to-serial converter.
	- **`TXD`** - This jumper can be cut to disconnect the `TX` signal of the DAN-F10N module from the CH340 USB-to-serial converter.

**`EXT_ANT`**
:   This jumper can be modified to control the source of the GNSS signals between the DAN-F10N module's integrated L1/L5 dual-band patch antenna or an external antenna connected to the board's U.FL connector.

	!!! info
		By default, the module's integrated L1/L5 dual-band patch antenna is utilized.

**`MEAS`**
:   This jumper can be cut for current measurments to the RT9080 voltage regulator from the USB-C connector or `5V` pin.

**`SHLD`**
:   This jumper can be cut to disconnect the shield of the USB-C connector from the board's ground plane.

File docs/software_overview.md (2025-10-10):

## USB Driver
The USB drivers for the CH340 USB-to-Serial converter can be downloaded from the [manufacturer's website](https://www.wch-ic.com/search?q=CH342&t=downloads).

<div class="grid cards" align="center" markdown>

-  :material-microsoft-windows: **Windows**

	---

	[:octicons-download-16:{ .heart } Download Page for `CH341SER.EXE`](https://www.wch-ic.com/download/file?id=65){ .md-button .md-button--primary target="blank" }

-  :material-apple: **MacOS**

	---

	[:octicons-download-16:{ .heart } Download Page for `CH341SER_MAC.ZIP`](https://www.wch-ic.com/download/file?id=334){ .md-button .md-button--primary target="blank" }

</div>

!!! info "Linux"
	A USB driver should not be required for most Linux based operating systems.

!!! tip "Default Settings"
	Below, are the default settings for the UART interface of the DAN-F10N GNSS module:

	- Baudrate: 38400bps
	- Data Bits: 8
	- Parity: No
	- Stop Bits: 1

## u-center 2 Software
[u-center 2](https://www.u-blox.com/en/product/u-center) is u-blox's software application for configuration, evaluation, and debugging of u-blox GNSS receivers and services. The software provides a relatively, simple graphics user interface to assess and test u-blox GNSS modules for navigation and positioning performance. It also allows users to define or apply GNSS product configurations for specific use cases. Saving, restoring, or sharing configurations between different products is easy.

<div class="grid cards" markdown>

<div markdown>

<article class="video-500px" style="text-align: center; margin: auto;" markdown>
<iframe src="https://www.youtube.com/embed/SCdULSkTcDM" title="u-blox u-center 2" frameborder="0" allow="accelerometer; autoplay; clipboard-write; encrypted-media; gyroscope; picture-in-picture" allowfullscreen></iframe>
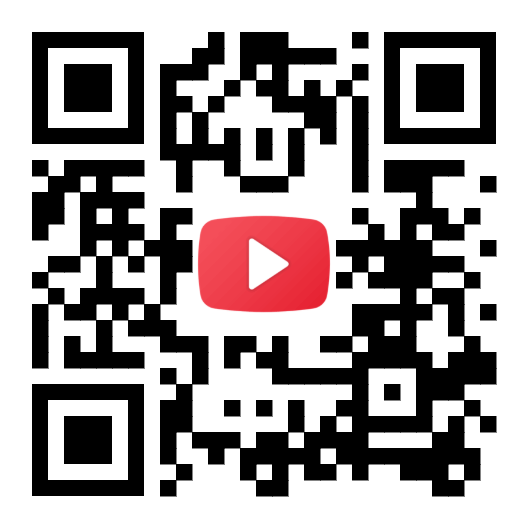
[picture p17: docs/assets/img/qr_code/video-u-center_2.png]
QR code

</article>

</div>

<div markdown>

- [Tutorials](https://www.u-blox.com/en/u-center2-tutorials)
- [User Manual](https://www.u-blox.com/en/info/u-center-2-user-guide)
	- [Connecting to a Device](https://www.u-blox.com/en/info/u-center-2-user-guide#32-connecting-a-device)
	- [Device Configuration](https://www.u-blox.com/en/info/u-center-2-user-guide#5-device-configuration)
	- [Views](https://www.u-blox.com/en/info/u-center-2-user-guide#8-views)
		- [Basic Data](https://www.u-blox.com/en/info/u-center-2-user-guide#84-data-view)
		- [Map](https://www.u-blox.com/en/info/u-center-2-user-guide#85-map-view)
		- [Satellites](https://www.u-blox.com/en/info/u-center-2-user-guide#87-satellite-signal-view)
		- [Deviation Plot](https://www.u-blox.com/en/info/u-center-2-user-guide#810-deviation-map-view)

</div>

</div>

!!! info "Product Compatibility"
	Gen 10 u-blox GNSS modules

### Installation
Installation of the [u-center 2 software](https://www.u-blox.com/en/product/u-center) is straight forward; simply, click on the button below to download the software. User should be aware that the first time the software accessed, they will need to either create or login to their existing u-blox account. If necessary, users can follow the video below or [reference the user manual](https://www.u-blox.com/en/info/u-center-2-user-guide#31-installing-u-center-2) for more instructions.

<div class="grid cards" markdown>

<div markdown>

<article class="video-500px" style="text-align: center; margin: auto;"  markdown>
<iframe src="https://www.youtube.com/embed/UY2XTb72SXA" title="How to download, install &amp; run u-center 2 (ver. 22.10.)" frameborder="0" allow="accelerometer; autoplay; clipboard-write; encrypted-media; gyroscope; picture-in-picture" allowfullscreen></iframe>
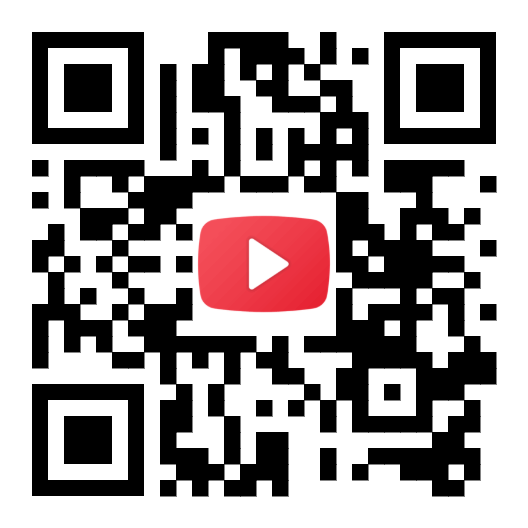
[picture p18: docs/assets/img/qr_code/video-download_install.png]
QR code

</article>

</div>

<div markdown>

<article style="text-align: center;" markdown>
[:octicons-download-16:{ .heart } Download the u-center 2 from u-blox](https://u-center2-updates.u-blox.com/u-center2-installer.exe){ .md-button .md-button--primary target="blank" }
</article>

???+ info "System Requirements"
	**Operating Systems**

	- Windows 10
	- Windows 11

!!! note "User Account Required"
	The first time that users access the software, they will need to either create or login to their existing u-blox account. This requires internet access to login through a web browser. Once the account has been verified, users will no longer need to login again; unless they log out from the u-center 2 software.

</div>

</div>

### Video Tutorials
Users should [reference the user manual](https://www.u-blox.com/en/info/u-center-2-user-guide#31-installing-u-center-2) for more information on the u-center 2 software. However, we have also linked their [webinar](https://www.u-blox.com/en/webinars/u-center2) and some videos from their [Youtube playlist](https://www.youtube.com/playlist?list=PLSzSoRUA4EXuo9NTsbTnK84MiKvbVCEKt) on u-blox's u-center 2 software application.

<div class="grid cards" align="center" markdown>

<article class="video-container" style="text-align: center;" markdown>
<iframe src="https://www.youtube.com/embed/ZYttFyZ_7Uo" title="Explore the possibilities of u-blox positioning device configuration with u-center 2" frameborder="0" allow="accelerometer; autoplay; clipboard-write; encrypted-media; gyroscope; picture-in-picture" allowfullscreen></iframe>
QR code
</article>

<article class="video-container" style="text-align: center;" markdown>
<iframe src="https://www.youtube.com/embed/sA5bCcolwag" title="Getting started with u-center 2 (ver. 22.10.)" frameborder="0" allow="accelerometer; autoplay; clipboard-write; encrypted-media; gyroscope; picture-in-picture" allowfullscreen></iframe>
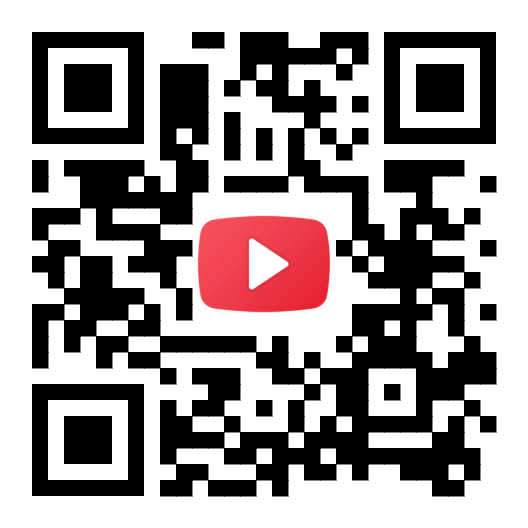
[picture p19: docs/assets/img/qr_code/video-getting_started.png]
QR code

</article>

<article class="video-container" style="text-align: center;" markdown>
<iframe src="https://www.youtube.com/embed/RonjsBTdW3A" title="Firmware update on u-center 2 (ver. 23.03.)" frameborder="0" allow="accelerometer; autoplay; clipboard-write; encrypted-media; gyroscope; picture-in-picture" allowfullscreen></iframe>
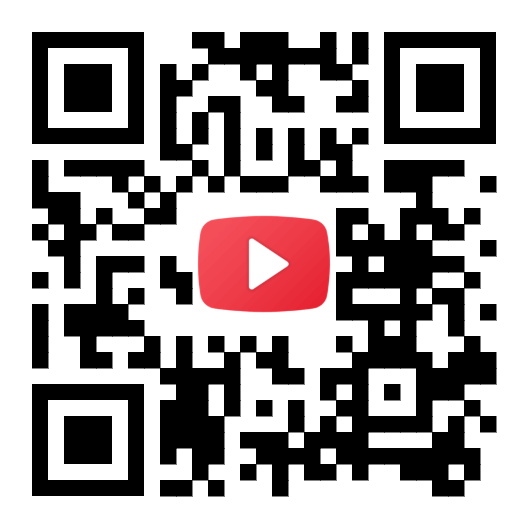
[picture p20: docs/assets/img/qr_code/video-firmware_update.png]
QR code

</article>

</div>

## Arduino IDE
!!! tip
	For first-time users, who have never programmed before and are looking to use the Arduino IDE, we recommend beginning with the <a href="https://www.sparkfun.com/sparkfun-inventor-s-kit-for-arduino-uno-v4-1.html">SparkFun Inventor's Kit (SIK)</a>, which is designed to help users get started programming with the Arduino IDE.

Most users may already be familiar with the Arduino IDE and its use. However, for those of you who have never heard the name *Arduino* before, feel free to check out the [Arduino website](https://www.arduino.cc/en/Guide/HomePage). To get started with using the Arduino IDE, check out our tutorials below:

<div class="grid cards" markdown align="center">

-  <a href="https://learn.sparkfun.com/tutorials/50"><figure markdown>
	What is an Arduino?
	</figure>

	---

	**What is an Arduino?**</a>

-  <a href="https://learn.sparkfun.com/tutorials/61"><figure markdown>
	Installing the Arduino IDE
	</figure>

	---

	**Installing the Arduino IDE**</a>

-  <a href="https://learn.sparkfun.com/tutorials/15"><figure markdown>
	Installing an Arduino Library
	</figure>

	---

	**Installing an Arduino Library**</a>

-  <a href="https://learn.sparkfun.com/tutorials/1265"><figure markdown>
	Installing Board Definitions in the Arduino IDE
	</figure>

	---

	**Installing Board Definitions in the Arduino IDE**</a>
</div>

### SparkFun u-blox GNSS v3 Library
The [SparkFun u-blox GNSS v3](https://github.com/sparkfun/SparkFun_u-blox_GNSS_v3) library can be installed from the library manager in the Arduino IDE by searching for:

	SparkFun u-blox GNSS v3

<div class="grid" markdown>

<div markdown>

<figure markdown>
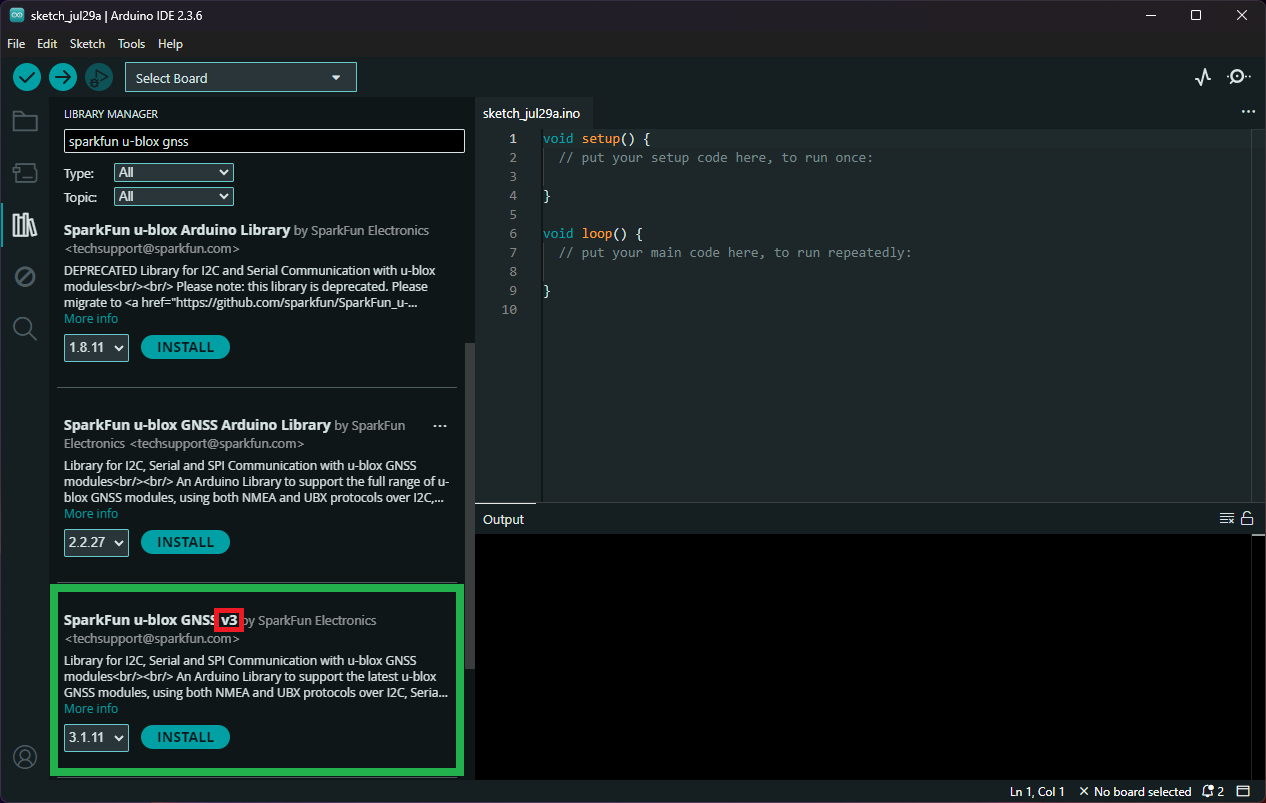
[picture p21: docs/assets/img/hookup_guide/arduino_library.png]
Library listed in the library manager of the Arduino IDE Click to enlarge

<figcaption markdown>SparkFun u-blox GNSS v3 library in the library manager of the Arduino IDE.</figcaption>
</figure>

</div>

<div markdown>

!!! tip "Manually Download the Arduino Library"
	For users who would like to manually download and install the library, the `*.zip` file can be accessed from the [GitHub repository](https://github.com/sparkfun/SparkFun_u-blox_GNSS_v3) or downloaded by clicking the button below.

	<article style="text-align: center;" markdown>
	[:octicons-download-16:{ .heart } Download the Arduino Library](https://github.com/sparkfun/SparkFun_u-blox_GNSS_v3/archive/refs/heads/main.zip){ .md-button .md-button--primary }
	</article>

</div>

</div>

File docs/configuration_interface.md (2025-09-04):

## Configuration Database

All configuration settings are stored in a database by the receiver.

The configuration database in the receiver's RAM holds the current configuration, which is used by the receiver at run-time. It is constructed on startup of the receiver from the configuration layers. The current configuration is called the RAM Layer. Any configuration in any layer is organized as Configuration Items, where each Configuration Item is referenced to by a unique Configuration Key ID and holds a single Configuration Value.

## Configuration Layers
The receiver has several configuration layers, some of the layers are read-only and others are modifiable. The layers are organized in terms of priority. Values in a high-priority layer replace values stored in a low-priority layers. At startup, the receiver reads all configuration layers and stacks up the items to create the current configuration, which is used by the receiver at run-time.

The following configuration layers are available (in order of priority, highest priority first):

1. **RAM**
:   This layer contains items stored in volatile RAM. This is the Current Configuration. The value of any item can be set by the user at run-time (see UBX protocol interface) and it is effective immediately.
1. **BBR**
:   This layer contains items stored in the battery-backed RAM. The contents in this layer are preserved as long as a battery backup supply is provided during off periods. The value of any item can be set by the user at run-time (see UBX protocol interface) and it becomes effective when the receiver is restarted.
1. **Flash**
:   This layer contains items stored permanently in the external flash memory. This layer is only available if there is a usable external flash memory. The value of any item can be set by the user at run-time (see UBX protocol interface) and it becomes effective when the receiver is restarted.
1. **Default**
:   This layer contains all items known to the running receiver software and their hard- coded default values. Data in this layer is not writable.

4.4.1 UBX protocol interface
The following UBX protocol messages are available to access the Configuration Database:
- `UBX-CFG-VALGET` to read configuration items from the database
- `UBX-CFG-VALSET` to set configuration items in the database
- `UBX-CFG-VALDEL` to delete configuration items from the database

4.7 Configuration reset behavior
The RAM layer is always rebuilt from the layers below when the chip's processor comes out from
reset. When using UBX-CFG-RST the processor goes through a reset cycle with these reset types
(resetMode field):
- `0x00` hardware reset (watchdog) immediately
- `0x01` controlled software reset
- `0x04` hardware reset (watchdog) after shutdown
See section Forcing a receiver reset in the integration manual.

### Configuration Items

| Group | Description |
| :---- | :--- |
| `CFG-HW` | Hardware configuration |
| `CFG-I2C` | Configuration of the I2C interface |
| `CFG-I2CINPROT` | Input protocol configuration of the I2C interface |
| `CFG-I2COUTPROT` | Output protocol configuration of the I2C interface |
| `CFG-MSGOUT` | Message output configuration |
| `CFG-NMEA` | NMEA protocol configuration |
| `CFG-RATE` | Navigation and measurement rate configuration |
| `CFG-SPI` | Configuration of the SPI interface |
| `CFG-SPIINPROT` | Input protocol configuration of the SPI interface |
| `CFG-SPIOUTPROT` | Output protocol configuration of the SPI interface |
| `CFG-TP` | Time pulse configuration |
| `CFG-UART1` | Configuration of the UART1 interface |
| `CFG-UART1INPROT`  | Input protocol configuration of the UART1 interface |
| `CFG-UART1OUTPROT` | Output protocol configuration of the UART1 interface |

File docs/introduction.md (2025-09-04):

<figure markdown>
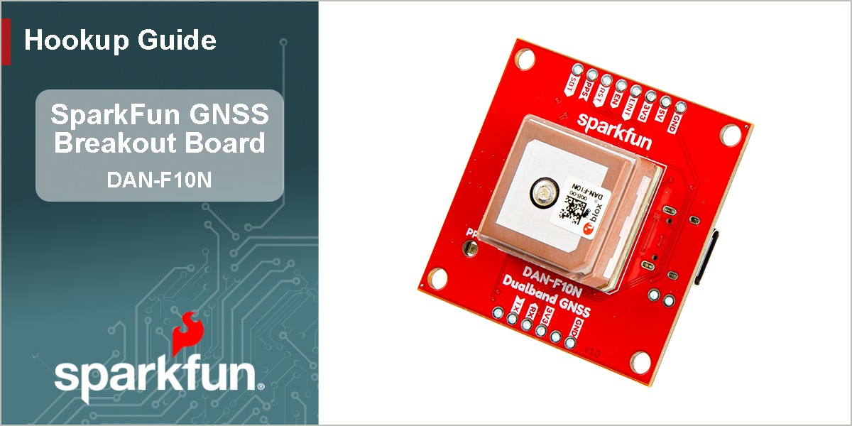
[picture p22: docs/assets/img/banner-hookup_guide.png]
Hookup Guide - Thumbnail

</figure>

---

# Introduction

<div class="grid cards desc" markdown>

-   <a href="https://www.sparkfun.com/sparkfun-dualband-l1-l5-gnss-breakout-dan-f10n.html">
	**Dualband L1/L5 GNSS Breakout - DAN-F10N**<br>
	**SKU:** GPS-28435

	---

	<figure markdown>
	Product Thumbnail
	</figure></a>

	<article style="text-align: center;" markdown>
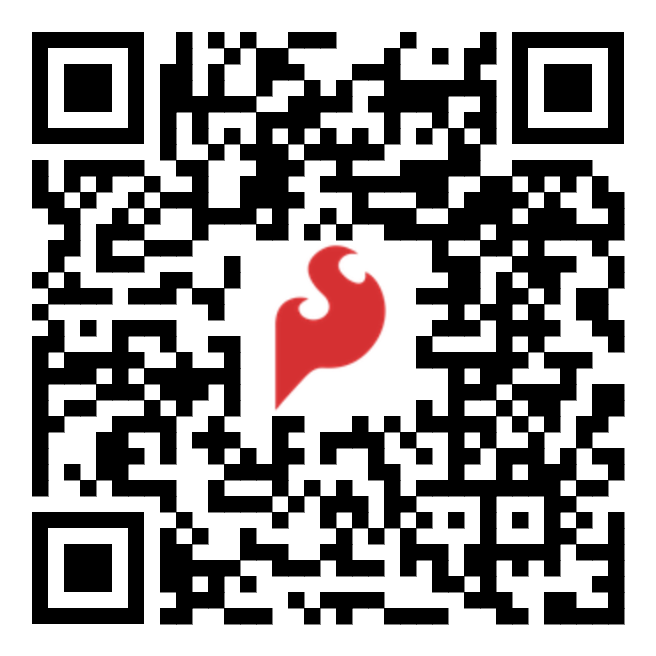
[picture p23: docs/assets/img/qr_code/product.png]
QR code to product page
	[Purchase from SparkFun :fontawesome-solid-cart-plus:{ .heart }](https://www.sparkfun.com/sparkfun-dualband-l1-l5-gnss-breakout-dan-f10n.html){ .md-button .md-button--primary }
	</article>

-   The SparkFun Dualband L1/L5 GNSS Breakout - DAN-F10N features u-blox's dual-band GNSS technology for the L1/L5 frequency bands. Their proprietary dual-band multipath mitigation technology enables the u-blox F10 GNSS engine to isolate the best signals from the L1 and L5 bands; delivering a solid meter-level position accuracy in challenging urban environments. Additionally, the DAN-F10N module's robust SAW-LNA-SAW RF architecture with an additional notch filter (LTE B13) on the L1 RF path ensures the best possible out-of-band interference mitigation from nearby cellular modems.

	The DAN-F10N GNSS module on this board comes with a 20 x 20 x 8 mm, integrated, Right Hand Circular Polarized (RHCP), L1/L5 dual-band patch antenna that offers the best compromise between size and performance. The patch antenna's wide beamwidth provides flexibility in the device's orientation; while alternatively, the module also has an antenna switch function to give users the option to utilize an external dual-band antenna, further increasing its utility.

	The DAN-F10N module is supported by the u-blox u-center 2 GNSS software for real-time performance analysis, receiver configuration, and data logging. The AssistNow Online, Offline, and Autonomous A-GNSS services can also be used with the module for faster satellite acquisition. Users can also interface with the GNSS module using NMEA 4.11 and UBX binary protocols.

	!!! note "GPS `L5` Signals"
		The GPS `L5` signals are currently, considered as *"pre-operational"* and not utilized by default in navigation solutions. However, it is possible override the receiver's configuration to evaluate the GPS `L5` signals. Please refer to the integration manual for more details.

		This is an operational limitation of the satellite/space segment and not an issue of the u-blox product.

</div>

In this guide we'll cover how to setup the DAN-F10N GNSS breakout board. To follow along with this tutorial, at a minimum, users will need the following items:

<div class="annotate" markdown>

- Computer with an operating system (OS) that is compatible with all the software installation requirements
- [USB 3.1 Cable A to C - 3 Foot](https://www.sparkfun.com/usb-3-1-cable-a-to-c-3-foot.html) - Used to interface with the DAN-F10N GNSS Breakout (1)
- [SparkFun Dualband L1/L5 GNSS Breakout - DAN-F10N](https://www.sparkfun.com/sparkfun-dualband-l1-l5-gnss-breakout-dan-f10n.html)

</div>

1. If your computer doesn't have a USB-A slot, then choose an appropriate cable or adapter.

<div class="grid cards" markdown>

-   <a href="https://www.sparkfun.com/usb-3-1-cable-a-to-c-3-foot.html">
	<figure markdown>
	USB 3.1 Cable A to C - 3 Foot
	</figure>

	---

	**USB 3.1 Cable A to C - 3 Foot**<br>
	CAB-14743</a>

-   <a href="https://www.sparkfun.com/sparkfun-dualband-l1-l5-gnss-breakout-dan-f10n.html">
	<figure markdown>
	Product Thumbnail
	</figure>

	---

	**Dualband L1/L5 GNSS Breakout - DAN-F10N**<br>
	GPS-28435</a>

</div>

## Section Topics
This guide is divided into three sections:

- The **Quickstart Guide** assumes a working knowledge of GNSS receiver, development boards, and the required software to program and/or configure them for your project's needs. It only covers basic hardware information and assembly instructions users would need to get started with this product.
- The **Hardware** section has two sub-sections that provide:
	- An overview of the board's design, major components, and interfaces. Refer to this page for information on the connectors, breakout pins, and jumpers.
	- Assembly instructions for this product's interfaces.
- The **Software** section has several sub-sections. The DAN-F10N module has numerous capabilities and a multitude of ways to configure and interface with them.
- In the **Resources** and **Support** sections, users can find the design files (KiCad files & schematic), relevant documentation (datasheets, white papers, etc.) and other helpful links on the Resources page. Lastly, the **Troubleshooting Tips** page includes helpful tips and instructions for how to receive technical support from SparkFun.

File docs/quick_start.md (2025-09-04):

---
icon: material/book-open-page-variant
---

<figure markdown>
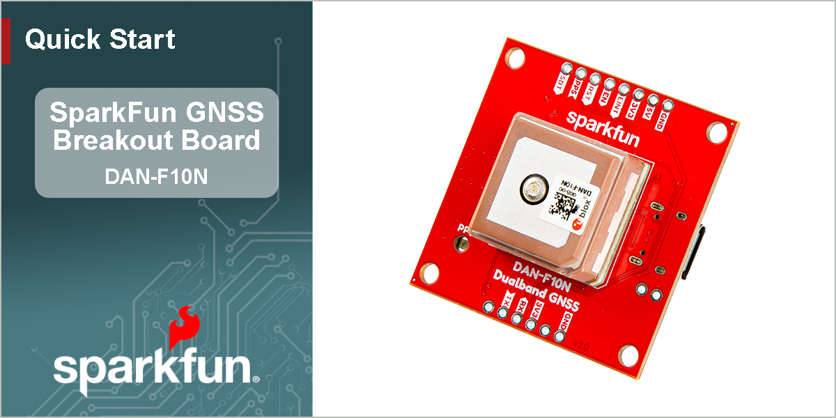
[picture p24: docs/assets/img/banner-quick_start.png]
Quick Start Guide - Thumbnail

</figure>

---

# Quick Start

<!-- Overview -->
--8<-- "./introduction.md:47:84"

<!-- Board Layout -->
--8<-- "hardware_overview.md:75:108"

<!-- USB Driver & u-center 2 -->
--8<-- "software_overview.md::19"
--8<-- "software_overview.md:36:37"
--8<-- "software_overview.md:78:110"

<!-- USB Programming -->
--8<-- "hardware_assembly.md::31"

## Getting Started
Users should [reference the user manual](https://www.u-blox.com/en/info/u-center-2-user-guide#31-installing-u-center-2) for more information on the u-center 2 software.

<div class="video-500px" style="text-align: center; margin: auto;" markdown>
<iframe src="https://www.youtube.com/embed/sA5bCcolwag" title="Getting started with u-center 2 (ver. 22.10.)" frameborder="0" allow="accelerometer; autoplay; clipboard-write; encrypted-media; gyroscope; picture-in-picture" allowfullscreen></iframe>
QR code
</div>

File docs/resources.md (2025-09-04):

## Product Resources

- :sfe: [Product Page](https://www.sparkfun.com/sparkfun-dualband-l1-l5-gnss-breakout-dan-f10n.html)
- :material-folder-cog: Design Files:
	- :fontawesome-solid-file-pdf: [Board Dimensions](./assets/board_files/dimensions.pdf)
	- :fontawesome-solid-file-pdf: [Schematic](./assets/board_files/schematic.pdf)
	- :material-folder-zip: [KiCad Files](./assets/board_files/kicad_files.zip)
	- :material-rotate-3d: [STEP File](./assets/3d_model/cad_model.step)
- [u-center 2 Software](https://www.u-blox.com/en/product/u-center)
	- [u-center 2 User Manual](https://www.u-blox.com/en/info/u-center-2-user-guide)
	- [Tutorials](https://www.u-blox.com/en/u-center2-tutorials)
- Component Documentation
	- DAN-F10N GNSS Module:
		- :fontawesome-solid-file-pdf: [Datasheet](https://content.u-blox.com/sites/default/files/documents/DAN-F10N_DataSheet_UBXDOC-963802114-13074.pdf)
		- :fontawesome-solid-file-pdf: [Product Summary](https://content.u-blox.com/sites/default/files/documents/DAN-F10N_ProductSummary_UBXDOC-963802114-13162.pdf)
		- :fontawesome-solid-file-pdf: [Integration Manual](https://content.u-blox.com/sites/default/files/documents/DAN-F10N_IntegrationManual_UBXDOC-963802114-13252.pdf)
	- :fontawesome-solid-file-pdf: [CH340 Datasheet](https://www.wch-ic.com/download/file?id=16)
- [Building a GNSS System](https://www.sparkfun.com/gps)
- [Qwiic Info Page](https://www.sparkfun.com/qwiic)
- :material-github: [Hardware Repo](https://github.com/sparkfun/SparkFun_GNSS_DAN-F10N)

### Additional Resources

- :material-account-supervisor: [SparkFun Technical Assistance](https://www.sparkfun.com/technical_assistance)

## 🏭&nbsp;Manufacturer's Resources
u-blox also provides great resources for the DAN-F10N GNSS receiver module:

- [DAN-F10N Product Page](https://www.u-blox.com/en/product/dan-f10n-module)
- :material-youtube: [u-blox YouTube Channel](https://www.youtube.com/@ublox)
	- :material-playlist-play: [Playlist: u-center 2](https://www.youtube.com/playlist?list=PLSzSoRUA4EXuo9NTsbTnK84MiKvbVCEKt)
- :material-head-question: [Support Page](https://portal.u-blox.com/s/)
- :material-folder-information: [Product Documentation](https://www.u-blox.com/en/product-resources?legacy=Current)
	- :material-head-lightbulb: [PNT Technologies](https://www.u-blox.com/en/positioning-and-location)
	- [u-center 2 Software](https://www.u-blox.com/en/product/u-center)
		- [u-center 2 User Manual](https://www.u-blox.com/en/info/u-center-2-user-guide)
		- [Tutorials](https://www.u-blox.com/en/u-center2-tutorials)

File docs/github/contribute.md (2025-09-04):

## Make an Augmentation!
Spot an improvement opportunity? Feel free to contribute to our open-source design and documentation. 

## :material-file-document-multiple:&nbsp;Improve our Documentation
All of this documentation can be modified by you! Please help us make it better.

- These pages are contained in the [`docs` folder](https://github.com/sparkfun/SparkFun_GNSS_DAN-F10N/tree/main/docs) of the [SparkFun GNSS Flex System repository](https://github.com/sparkfun/SparkFun_GNSS_DAN-F10N).

<!-- ### :material-source-pull:&nbsp;Submit a Correction -->
### Submit a Correction

1. With a GitHub account, [fork this repository](https://github.com/sparkfun/SparkFun_GNSS_DAN-F10N/fork).
1. Add your corrections or improvements to the markdown file.
1. File a pull request with your changes, and enjoy making the ~~words~~ ~~worlds~~ world a better place.
	- Once received, the documentation specialist will automatically be notified.
	- We will review your suggested improvements to make sure they are correct and fit within our documentation standards.

## :material-cog:&nbsp;Improve our Hardware Design
All of our designs are open-source! Please help us make it better.

- Our board design files are contained in the `/Hardware` directories of the [SparkFun GNSS Flex System repository](https://github.com/sparkfun/SparkFun_GNSS_DAN-F10N).

<!-- ### :material-source-pull:&nbsp;Submit a Design Enhancement -->
### Submit a Design Enhancement

1. With a GitHub account, [fork this repository](https://github.com/sparkfun/SparkFun_GNSS_DAN-F10N/fork).
1. Add your design augmentation(s)
1. File a pull request with your changes, and enjoy making the ~~words~~ ~~worlds~~ world a better place.
	1. Once received, the engineer in charge of the original design will automatically be notified.
	1. We will review your suggested improvement(s) to verify that they are within our board design standards and meet our product design requirements.
	1. If approved, we will flag these changes for our next board revision. Congrats! 🍻

		!!! info
			Even if your suggestion is accepted, these changes may not be immediately available for purchase. We may have to cycle through our current product inventory first.

## Contributors&nbsp;:clap:
Let's provide some recognition to the contributors for this project!

GitHub Contributors Image
<br>


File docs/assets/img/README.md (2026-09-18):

img directory
====================
This folder should contain the images for the product documentation

General Images
--------------

- `favicon.ico` - SparkFun flame logo (favicon)
- `banner.psd` - Photoshop Template to generate banner images
- `banner-*.png` - Banner image for the product manual, hookup guide, and/or quick start guide

Directory
---------

- `graphical_datasheet` - Files to generate graphical datasheet
- `hookup_guide` - Images for the hookup guide pages
- `qr_code` - QR code images
- `qwiic` - Images for Qwiic Banner

QR Codes
--------

- [QR code generator](https://qrgenerator.org/)
	- Flame Color: #E0311D
	- Frame Color: #3C464D
- [Remove meta data from svg](https://jakearchibald.github.io/svgomg/)

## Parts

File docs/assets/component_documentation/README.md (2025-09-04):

SparkFun Documentation
=======================

This directory should include any necessary datasheets, example number crunching, etc.

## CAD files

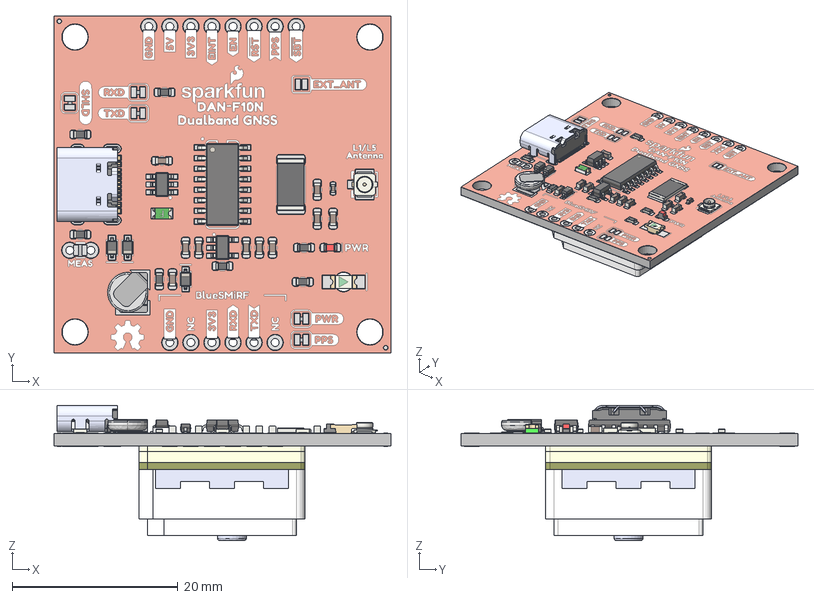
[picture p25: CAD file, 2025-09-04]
docs/assets/3d_model/cad_model.step
40.6 x 40.6 x 16.3 mm
C_0603_1608Metric x 10
USB4105GFA_USB4105GFA
D_SOD-323 x 3
R_0603_1608Metric x 7
LED_0603_1608Metric_Red
C_0402_1005Metric
SOT-23-5
Fuse_0805_2012Metric
R_2512_6332Metric
SO-16_3.9x9.9mm_P1.27mm
U.FL
SOT-23-6
isolator
cleme
Anode
Negative
Positive
LED_1206_3216Metric_Castellated_Green
DAN_TAO_Taoglas_Antenna
DAN_TAO_DAN-F10N_Interposer_DAN-F10N_Interposer_BOARD
DAN_TAO_DAN-F10N_Eiplus_Main_Board_DAN-F10N_Eiplus_Main_Board_BOARD
DAN_TAO_Bottom Layer_DAN-F10N_Eiplus_Main_Board_DAN-F10N_Eiplus_Main_Board.sldasm_0
DAN_TAO_Bottom Layer_DAN-F10N_Eiplus_Main_Board_DAN-F10N_Eiplus_Main_Board.sldasm_1
DAN_TAO_Bottom SolderMask_DAN-F10N_Eiplus_Main_Board_DAN-F10N_Eiplus_Main_Board.sldasm_ 0
SparkFun_GNSS_DAN-F10N_pad
SparkFun_GNSS_DAN-F10N_silkscreen
SparkFun_GNSS_DAN-F10N_soldermask
SparkFun_GNSS_DAN-F10N_PCB

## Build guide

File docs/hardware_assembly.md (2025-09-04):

## USB Programming
The USB connection is utilized for configuration and serial communication. Users only need to connect their DAN-F10N Dualband L1/L5 GNSS breakout board to a computer using a USB-C cable.

<div class="grid" markdown>

<div markdown>

<figure markdown>
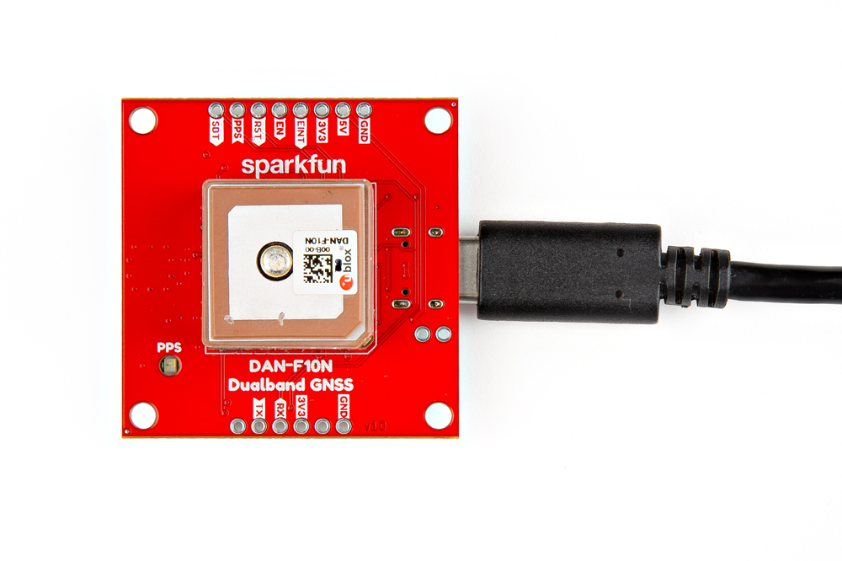
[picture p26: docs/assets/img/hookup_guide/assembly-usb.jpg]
USB connection

<figcaption markdown>The DAN-F10N Dualband L1/L5 GNSS breakout board with a USB-C cable attached.</figcaption>
</figure>

</div>

<div markdown>

!!! tip "USB Driver"
	Users will need to install a USB driver before they can interact with the GNSS module. For more details, please refer to the [**USB Driver** section of the Software page](software_overview.md/#usb-driver).

!!! info "Default Settings"
	- Baudrate: 38400bps
	- Data Bits: 8
	- Parity: No
	- Stop Bits: 1

</div>

</div>

## External Antenna

<div class="grid" markdown>

<div markdown>

<figure markdown>
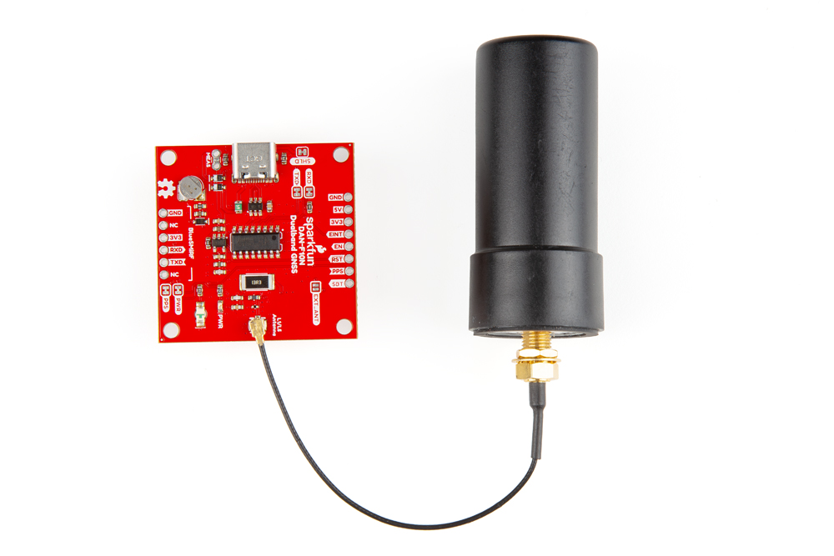
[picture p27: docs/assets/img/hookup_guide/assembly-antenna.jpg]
GNSS antenna connection

<figcaption markdown>Soldering the `EXT_ANT` jumper on the DAN-F10N GNSS breakout board to utilize the GNSS antenna attached to the U.FL connector.</figcaption>
</figure>

</div>

<div markdown>

In order to receive [GNSS](https://en.wikipedia.org/wiki/Satellite_navigation "Global Navigation Satellite System") signals, a compatible antenna is required. Users have the option of utilizing the integrated L1/L5 dual-band patch antenna or an external GNSS antenna. An external antenna can be connected to the U.FL connector on the board with an [U.FL to SMA adapter cable](https://www.sparkfun.com/sma-to-u-fl-cable-150mm.html). In order to trigger the RF switch inside the DAN-F10N GNSS module to utilize the U.FL connector as its signal source, the `EXT_ANT` jumper must be modified.

!!! tip
	For the best performance, we recommend users choose a compatible L1/L5 GNSS antenna and utilize a low-loss cable. Also, don't forget that GNSS signals are fairly weak and can't penetrate buildings or dense vegetation. The GNSS antenna should have an unobstructed view of the sky.

??? note "Never modified a jumper before?"
	Check out our <a href="https://learn.sparkfun.com/tutorials/664">Jumper Pads and PCB Traces tutorial</a> for a quick introduction!

	<article class="grid cards" markdown align="center">

	-   <a href="https://learn.sparkfun.com/tutorials/664">
		<figure markdown>
		Tutorial thumbnail
		</figure>

		---

		**How to Work with Jumper Pads and PCB Traces**</a>

	</article>

</div>

</div>

## Breakout Pins
The [PTH](https://en.wikipedia.org/wiki/Through-hole_technology "Plated Through Holes") pins on the DAN-F10N Dualband L1/L5 GNSS breakout board are broken out into 0.1"-spaced pins on the outer edges of the board.

??? note "New to soldering?"
	If you have never soldered before or need a quick refresher, check out our [How to Solder: Through-Hole Soldering](https://learn.sparkfun.com/tutorials/how-to-solder-through-hole-soldering) guide.

	<div class="grid cards" markdown align="center">

	-   <a href="https://learn.sparkfun.com/tutorials/5">
		<figure markdown>
		Tutorial thumbnail
		</figure>

		---

		**How to Solder: Through-Hole Soldering**</a>

	</div>

<div class="grid" markdown>

<div markdown>

**Headers**

---

When selecting headers, be sure you are aware of the functionality you require.

<figure markdown>
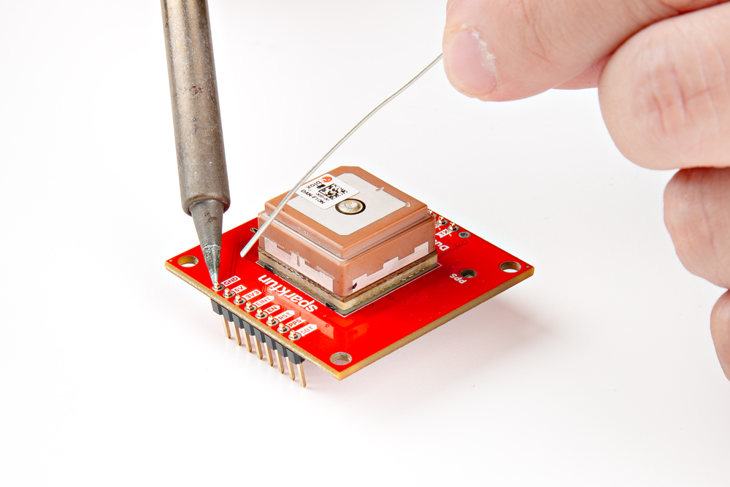
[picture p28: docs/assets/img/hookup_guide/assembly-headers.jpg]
Soldering headers

<figcaption markdown>Soldering headers to the DAN-F10N GNSS breakout board.</figcaption>
</figure>

</div>

<div markdown>

**Hookup Wires**

---

For a more permanent connection, users can solder wires directly to the board.

<figure markdown>
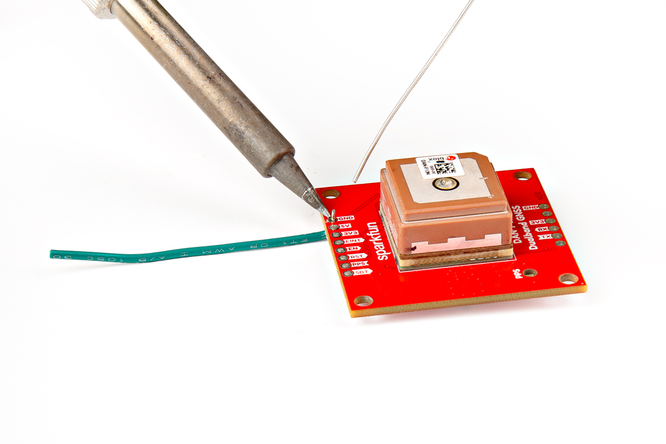
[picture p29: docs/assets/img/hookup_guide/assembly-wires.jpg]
Soldering wires

<figcaption markdown>Soldering wires to the DAN-F10N GNSS breakout board.</figcaption>
</figure>

</div>

</div>

### BlueSMiRF Header Pins
One of the two sets of [PTH](https://en.wikipedia.org/wiki/Through-hole_technology "Plated Through Holes") pins on the DAN-F10N Dualband L1/L5 GNSS breakout board is labeled `BlueSMiRF`. This set of header pins breaks out the UART interface of the DAN-F10N module, which can be connected to a microcontroller or RF transceiver; such as the [BlueSMiRF *v2*](https://www.sparkfun.com/sparkfun-bluesmirf-v2-headers.html), Bluetooth^&reg;^ serial link. The BlueSMiRF *v2* comes in two variations, with [PTH pins](https://www.sparkfun.com/sparkfun-bluesmirf-v2.html) or [male header pins](https://www.sparkfun.com/sparkfun-bluesmirf-v2-headers.html). Users can directly solder the PTH variant to the board with [male headers](https://www.sparkfun.com/break-away-headers-straight.html), for a more permanent installation; otherwise, for more flexibility, a [stackable header](https://www.sparkfun.com/arduino-stackable-header-6-pin.html) can be utilized.

<div class="grid" markdown>

<div markdown>

<figure markdown>
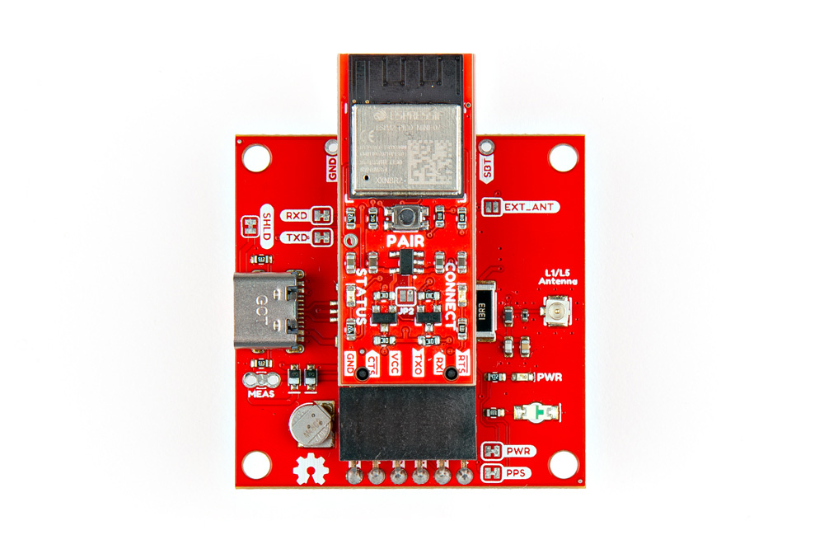
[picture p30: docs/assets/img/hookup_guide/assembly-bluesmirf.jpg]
BlueSMiRF header

<figcaption markdown>Connecting the BlueSMiRF serial link to the BlueSMiRF header on the DAN-F10N GNSS breakout board.</figcaption>
</figure>

</div>

<div markdown>

!!! info "Default Settings"
	- Baudrate: 38400bps
	- Data Bits: 8
	- Parity: No
	- Stop Bits: 1

!!! warning "Bus Contention"
	To avoid [bus contention](https://en.wikipedia.org/wiki/Bus_contention) issues with the USB-C connection, users may want to use the [`RXD` and `TXD` jumpers](hardware_overview.md#jumpers) to disconnect the CH340 USB-to-serial converter from the UART interface of the DAN-F10N GNSS module.

</div>

</div>

When connecting the DAN-F10N Dualband L1/L5 GNSS breakout board to another device, users need to be aware of the pin connections and voltage ranges of the products. Below, is a table of the pin connections that users can reference.

<article style="text-align: center;" markdown>

<table border="1" markdown>
<tr markdown>
<th style="vertical-align:middle;">Pin Number</th>
<td align="center" markdown>
	**1**<br>
	*(Left Side)*
</td>
<td align="center" markdown>**2**</td>
<td align="center" markdown>**3**</td>
<td align="center" markdown>**4**</td>
<td align="center" markdown>**5**</td>
<td align="center" markdown>
	**6**<br>
	*(Right)*
</td>
</tr>
<tr markdown>
<th style="vertical-align:middle;">Label</th>
<td align="center" markdown>`NC`</td>
<td align="center" markdown>`TXD`</td>
<td align="center" markdown>`RXD`</td>
<td align="center" markdown>`3V3`</td>
<td align="center" markdown>`NC`</td>
<td align="center" markdown>`GND`</td>
</tr>
<tr markdown>
<th style="vertical-align:middle;">Function</th>
<td align="center" markdown></td>
<td align="center" markdown>UART - Transmit</td>
<td align="center" markdown>UART - Receive</td>
<td align="center" markdown>Output Voltage: **3.3V**</td>
<td align="center" markdown></td>
<td align="center" markdown>Ground</td>
</tr>
</table>

</article>

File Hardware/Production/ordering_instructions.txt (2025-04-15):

Ordering Instructions:
Panel dimensions: 148.81 x 177.76 mm.
Material: TG135
Solder Mask: Red
Silkscreen Color: White
Layers: 4
Finish: HASL Lead-Free
Thickness: 1.6mm
Inner Copper Weight: 0.5oz
Outer Copper Weight: 1oz
Minimum track width: 0.15mm (6.00mil)
Minimum via drill: 0.30mm (11.81mil)
No Clean Process

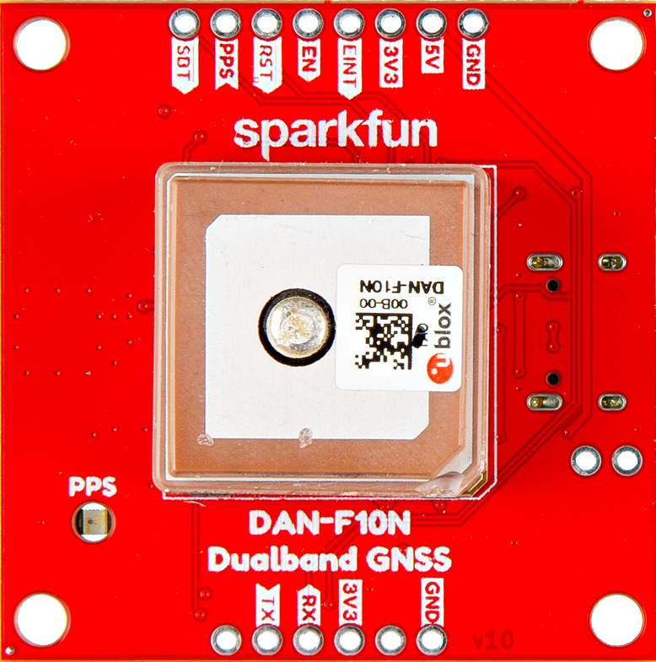
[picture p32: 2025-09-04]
docs/assets/img/hookup_guide/top.png

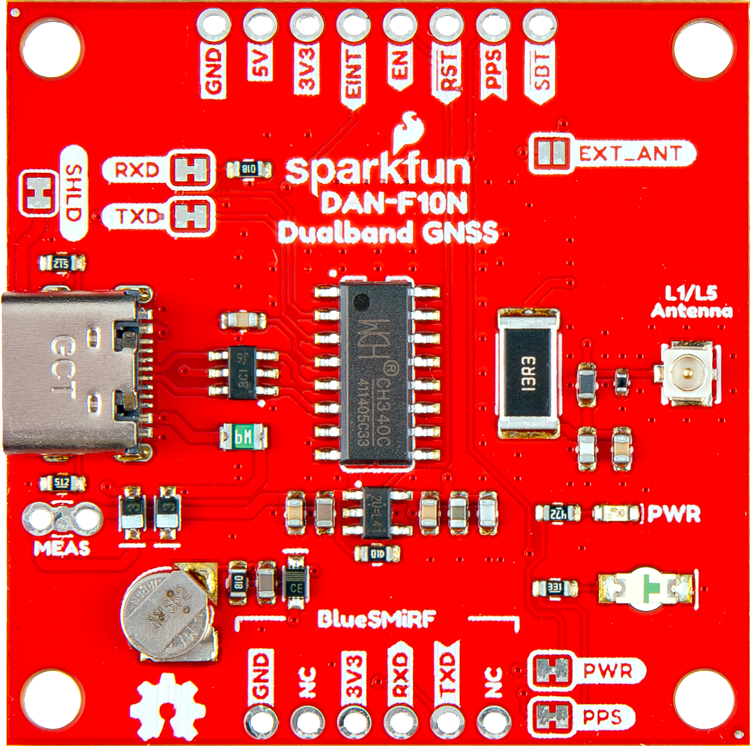
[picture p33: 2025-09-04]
docs/assets/img/hookup_guide/bottom.png

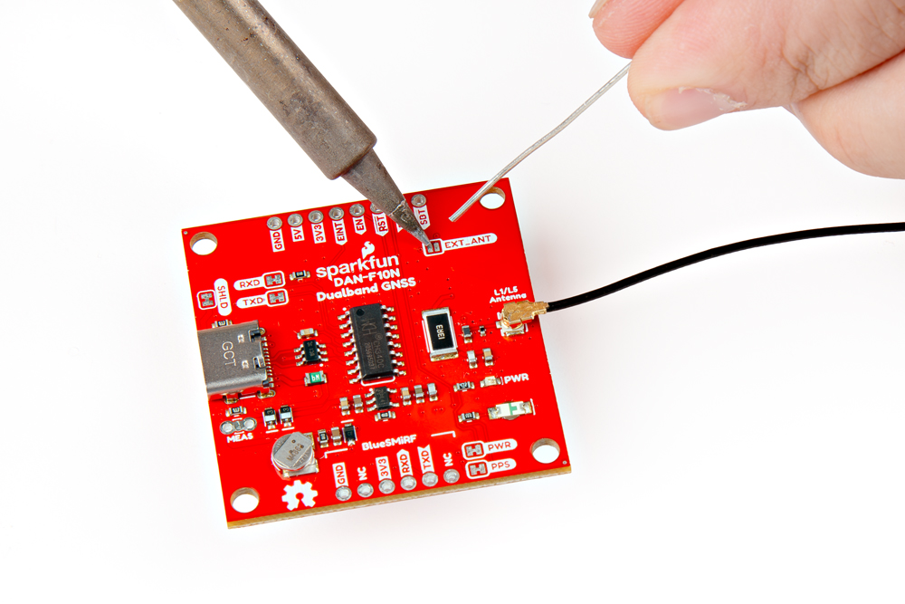
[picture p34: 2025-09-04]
docs/assets/img/hookup_guide/assembly-jumper.jpg

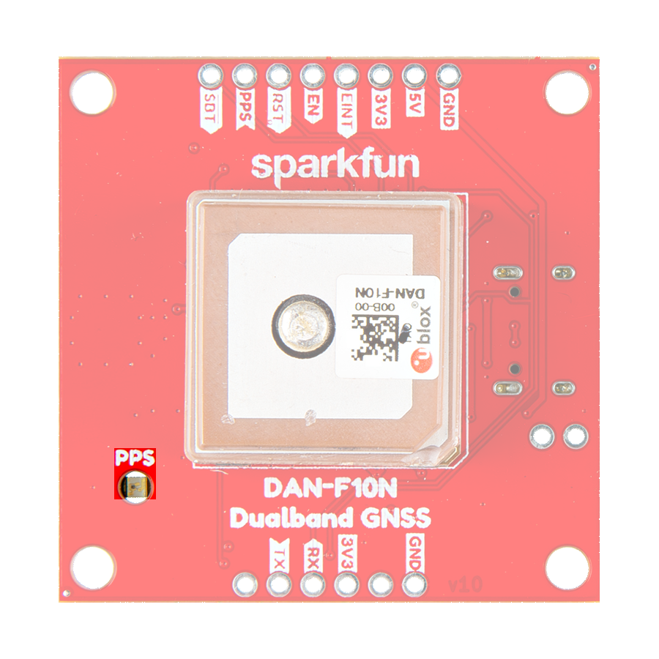
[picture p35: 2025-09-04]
docs/assets/img/hookup_guide/LEDs-PPS.png

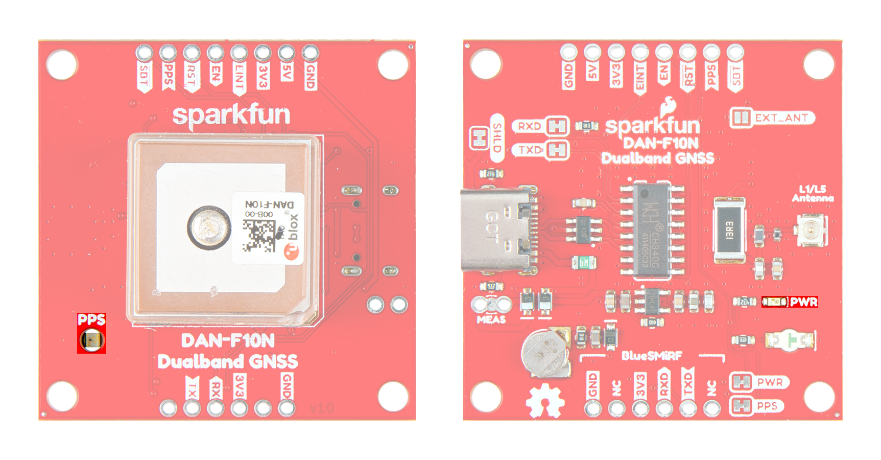
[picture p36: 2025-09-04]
docs/assets/img/hookup_guide/LEDs2.png

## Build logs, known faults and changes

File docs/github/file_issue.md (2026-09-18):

## Need Assistance?

<!-- Technical Assistance Box -->
!!! warning "Need Help?"
	If you need technical assistance or more information on a product that is not working as you expected, we recommend heading on over to the [SparkFun Technical Assistance](https://www.sparkfun.com/technical_assistance) page for some initial troubleshooting. This **Submit Issues** page is not where users should seek assistance.

	<article style="text-align: center;" markdown>
	[SparkFun Technical Assistance Page](https://www.sparkfun.com/technical_assistance){ .md-button .md-button--primary }
	</article>

	If you can't find what you need there, the [SparkFun Forums](https://community.sparkfun.com) is a great place to search the product forums and ask questions.

	!!! info "Account Registration Required"
		For your first visit to our forum, you'll need to create a [Forum Account](https://community.sparkfun.com/signup) to post questions.

## Did we make a mistake?
Spot something wrong? Please let us know. 

### Discrepancies in the Documentation
All of our documentation can be modified by you! Please help us make it better.

- The documentation files for these pages are contained in the [`docs` folder](https://github.com/sparkfun/SparkFun_GNSS_DAN-F10N/tree/main/docs) of the [SparkFun GNSS Flex System repository](https://github.com/sparkfun/SparkFun_GNSS_DAN-F10N).

#### 🔍 Spot something wrong?
If a section of the documentation is incorrect, please [open an issue](https://github.com/sparkfun/SparkFun_GNSS_DAN-F10N/issues) and let us know.

#### Do you have a suggested correction?

1. With a GitHub account, [fork this repository](https://github.com/sparkfun/SparkFun_GNSS_DAN-F10N/fork).
1. Add your correction(s) or improvement(s) to the markdown file(s)
1. File a pull request with your changes, and enjoy making the ~~words~~ ~~worlds~~ world a better place.
	- Once received, the documentation specialist will automatically be notified.
	- We will review your suggested improvement(s) to make sure they are correct and fit within our documentation standards.

### Problems in the Hardware Design
All of our designs are open-source! Please help us make it better.

- Our board design files are contained in the `/Hardware` directories of the [SparkFun GNSS Flex System repository](https://github.com/sparkfun/SparkFun_GNSS_DAN-F10N).

#### Does something not make sense? 🤔
If part of the design is confusing, please [open an issue](https://github.com/sparkfun/SparkFun_GNSS_DAN-F10N/issues) and let us know.

#### Did we forget to include an important function of the board? 🤦
If part of the board's functionality is missing, please [open an issue](https://github.com/sparkfun/SparkFun_GNSS_DAN-F10N/issues) and file a feature request.

!!! tip "Design Considerations"
	Please keep in mind that we may intentionally exclude certain functions of the board to meet our product design requirements.

	- *For example, our Qwiic Micro boards are intended to fit on a small board layout and only use I^2^C communication; therefore, we may not have the SPI and interrupt pins available for users.*

#### Do you wish to contribute directly to improving the board design?

1. With a GitHub account, [fork this repository](https://github.com/sparkfun/SparkFun_GNSS_DAN-F10N/fork).
1. Add your design augmentation(s)
1. File a pull request with your changes, and enjoy making the ~~words~~ ~~worlds~~ world a better place.
	1. Once received, the engineer in charge of the original design will automatically be notified.
	1. We will review your suggested improvement(s) to verify that they are within our board design standards and meet our product design requirements.
	1. If approved, we will flag these changes for our next board revision. Congrats! 🍻

		!!! info
			Even if your suggestion is accepted, these changes may not be immediately available for purchase. We may have to cycle through our current product inventory first.

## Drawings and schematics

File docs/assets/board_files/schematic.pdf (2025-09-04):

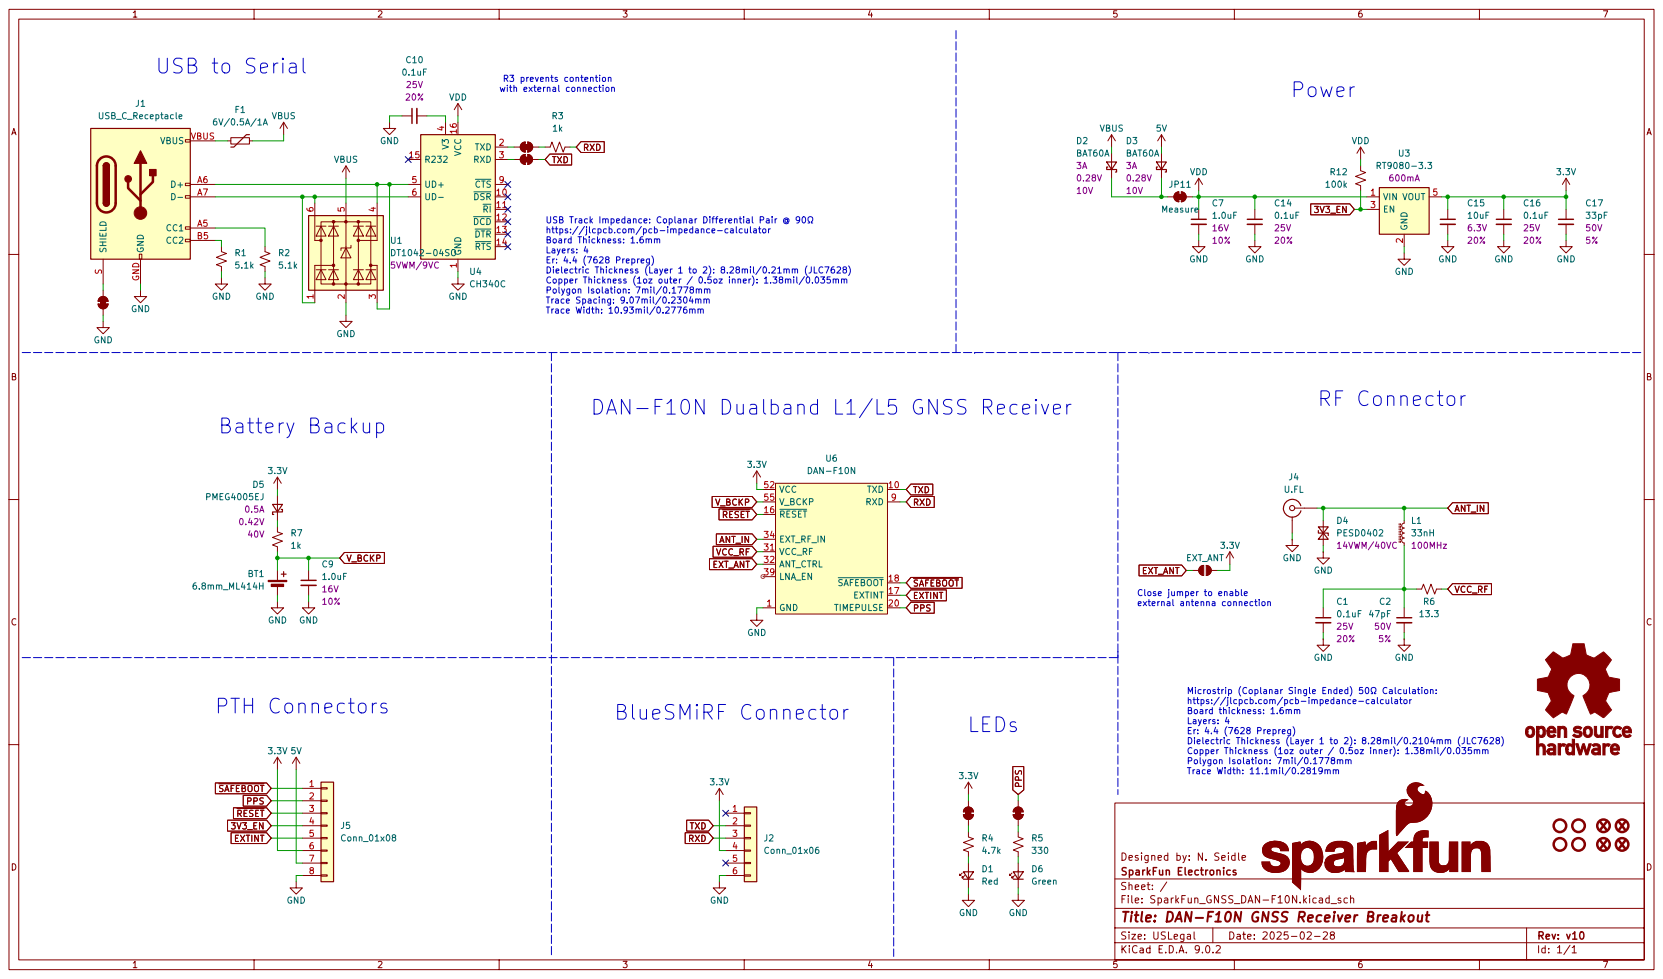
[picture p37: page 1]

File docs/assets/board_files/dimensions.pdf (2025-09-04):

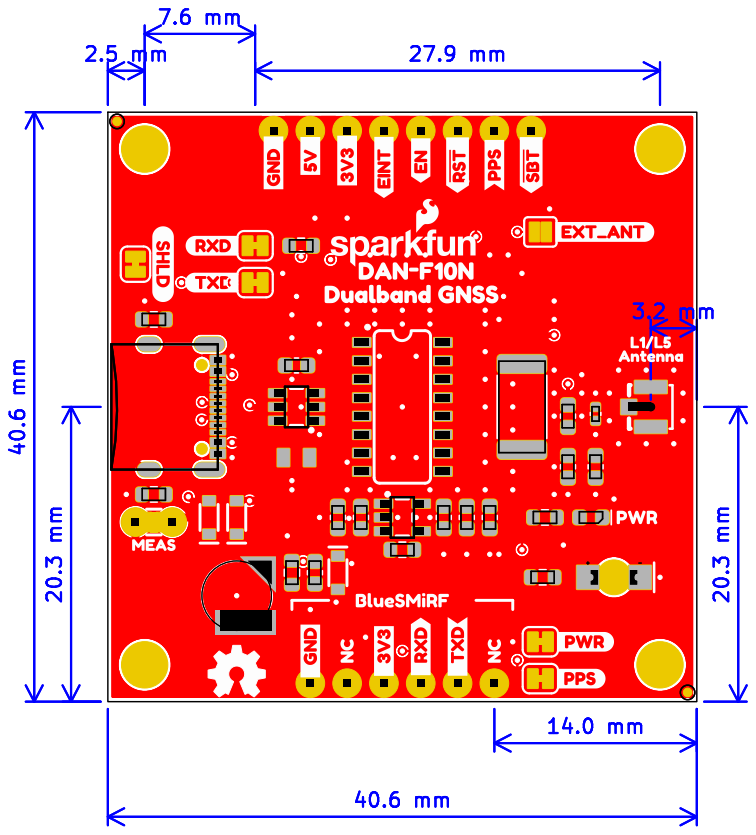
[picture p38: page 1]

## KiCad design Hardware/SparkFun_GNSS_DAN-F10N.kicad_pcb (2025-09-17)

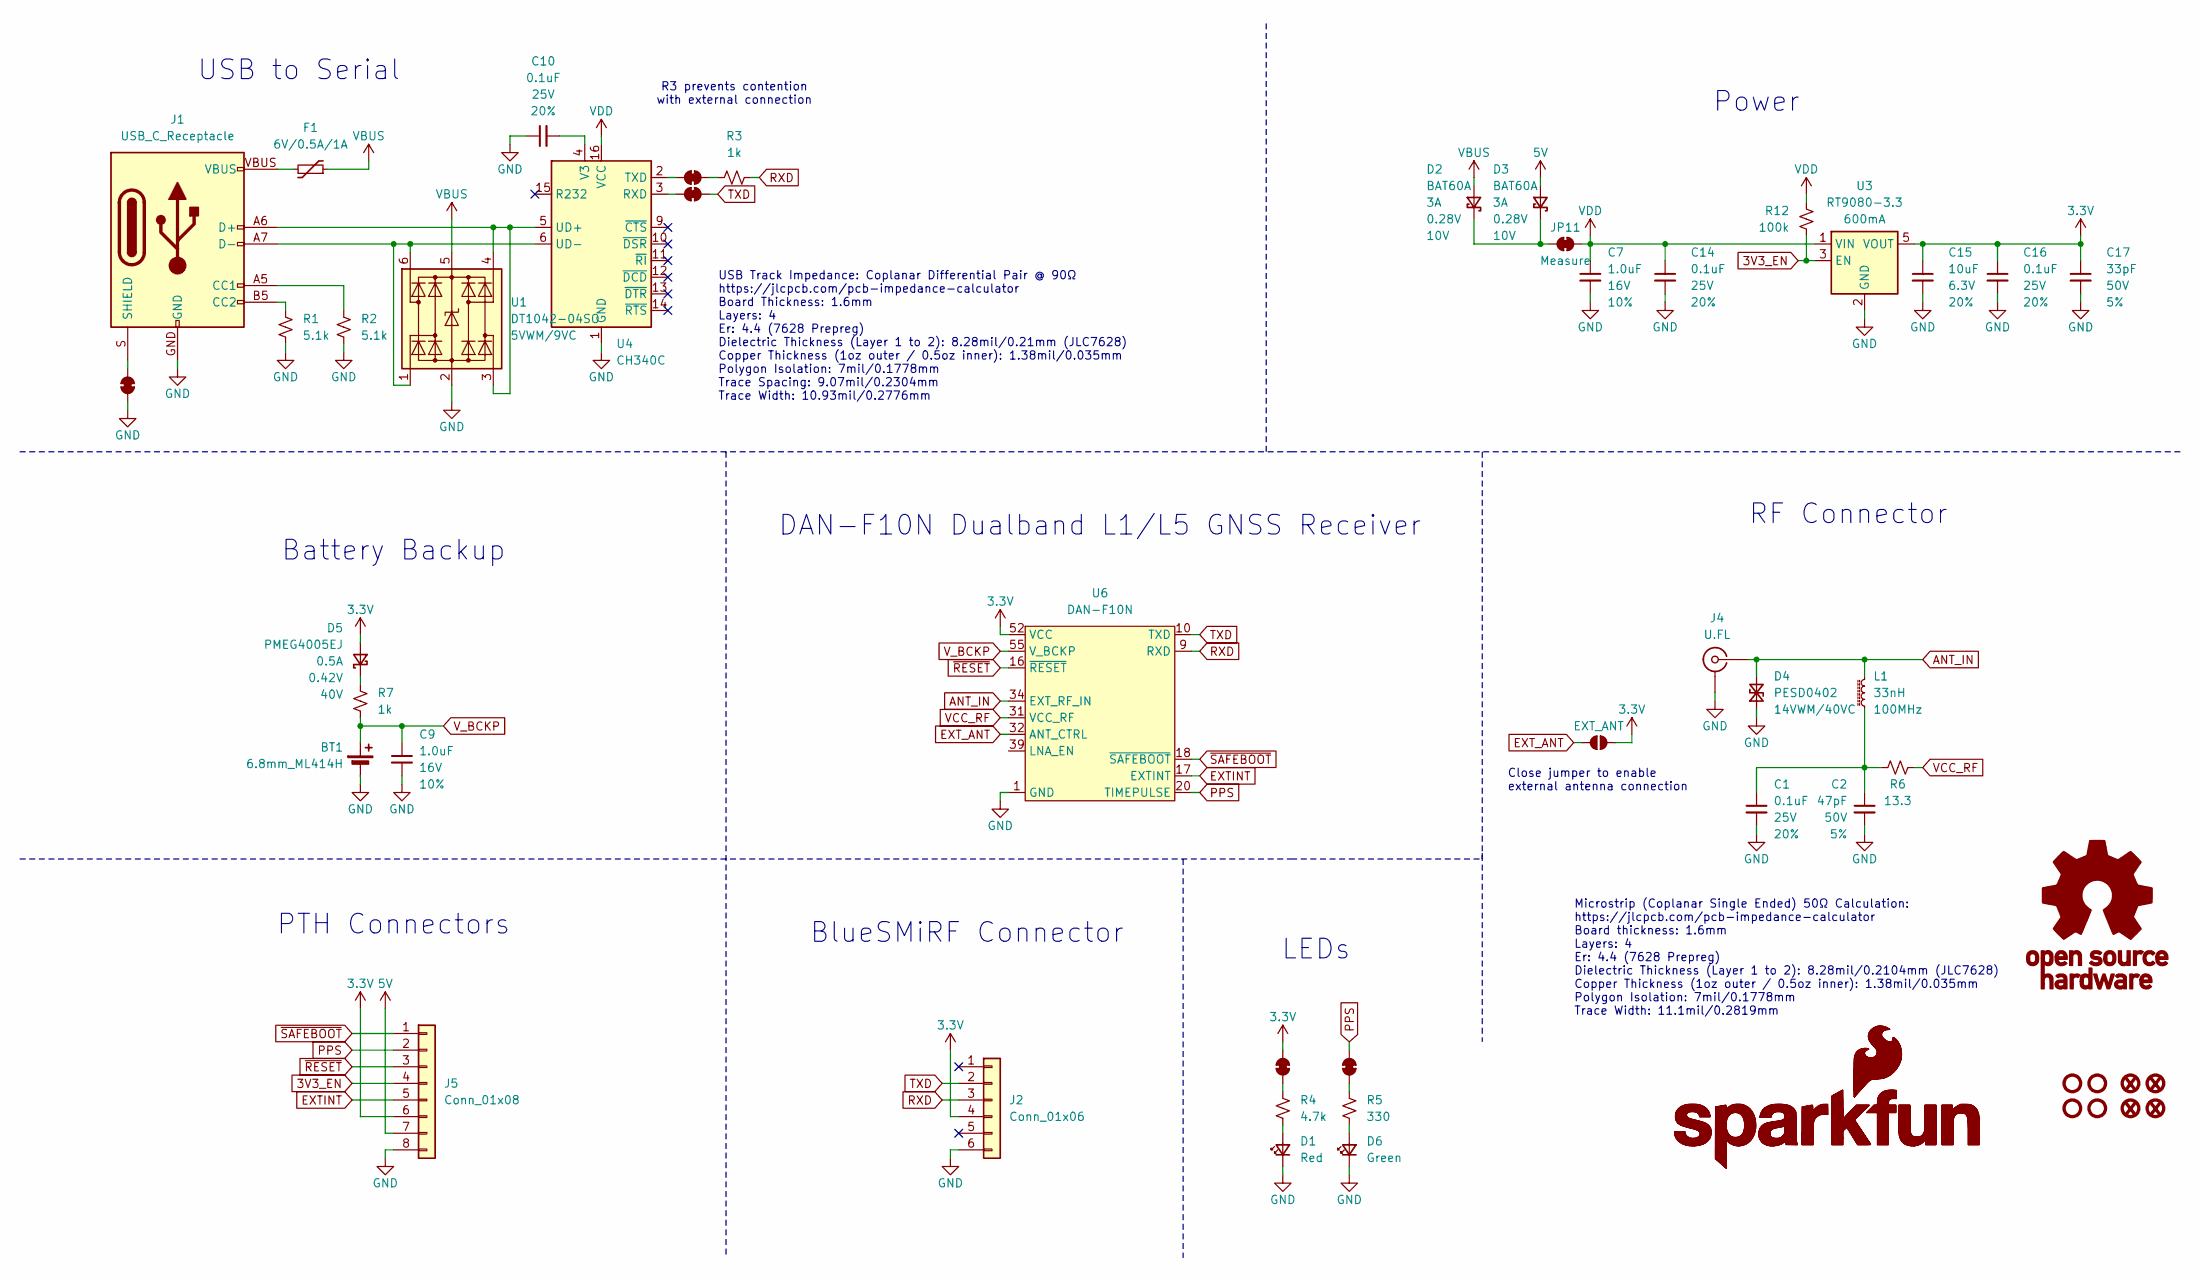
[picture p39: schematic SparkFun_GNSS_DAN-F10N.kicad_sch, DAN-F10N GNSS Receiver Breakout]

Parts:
BT1: 6.8mm_ML414H; ML414H_IV01E
C1, C10, C14, C16: 0.1uF; C_0603_1608Metric; Voltage 25V; Tolerance 20%
C2: 47pF; C_0603_1608Metric; Voltage 50V; Tolerance 5%
C7, C9: 1.0uF; C_0603_1608Metric; Voltage 16V; Tolerance 10%
C15: 10uF; C_0603_1608Metric; Voltage 6.3V; Tolerance 20%
C17: 33pF; C_0603_1608Metric; Voltage 50V; Tolerance 5%
D1: Red; LED_0603_1608Metric_Red
D2, D3: BAT60A; SOD-323
D4: PESD0402; C_0402_1005Metric; Rating 14VWM/40VC
D5: PMEG4005EJ; SOD-323
D6: Green; LED_1206_Bottom_Green
F1: 6V/0.5A/1A; 0805
FID1, FID2, FID3, FID4: Fiducial_0.5mm; Fiducial_0.5mm_Mask1mm
G1: OSHW_Logo; Creative_Commons_License
G3: SparkFun_Logo
G5: SparkFun_Logo; SparkFun_Logo_8mm
J1: USB_C_Receptacle; USB-C_16
J2: Conn_01x06; 1x06
J4: U.FL
J5: Conn_01x08; 1x08
JP1: EXT_ANT; Jumper_2_NO
JP2, JP3, JP7, JP9, JP10: Jumper_2_NC_Trace
JP11: Measure; Jumper_2_PTH_SMD_Combo-NC
L1: 33nH; C_0603_1608Metric
R1, R2: 5.1k; R_0603_1608Metric
R3, R7: 1k; R_0603_1608Metric
R4: 4.7k; R_0603_1608Metric
R5: 330; R_0603_1608Metric
R6: 13.3; R_2512_6332Metric
R12: 100k; R_0603_1608Metric
ST1, ST2, ST3, ST4: Standoff
U1: DT1042-04SO; SOT23-6; Rating 5VWM/9VC
U3: RT9080-3.3; SOT23-5
U4: CH340C; SO-16
U6: DAN-F10N; u-blox_DAN-F10N

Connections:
3.3V: C15.1, C16.1, C17.1, D5.2 (A), J2.4, J5.6, JP1.1 (A), JP2.2 (B), U3.5 (VOUT), U6.52 (VCC), U6.53 (VCC)
3V3_EN: J5.4, R12.1, U3.3 (EN)
5V: D3.2 (A), J5.7
ANT_IN: D4.2 (A2), J4.1 (In), L1.2, U6.34 (EXT_RF_IN)
EXTINT: J5.5, U6.17 (EXTINT)
EXT_ANT: JP1.2 (B), U6.32 (ANT_CTRL)
GND: BT1.-, C1.2, C2.2, C7.2, C9.2, C10.1, C14.2, C15.2, C16.2, C17.2, D1.1 (K), D4.1 (A1), D6.1 (K), J1.GND, J2.6, J4.2 (Ext), J5.8, JP7.1 (A), R1.1, R2.1, U1.2 (GND), U3.2 (GND), U4.1 (GND), U6.1 (GND), U6.2 (GND), U6.3 (GND), U6.4 (GND), U6.5 (GND), U6.6 (GND), U6.7 (GND), U6.8 (GND), U6.13 (GND), U6.14 (GND), U6.15 (GND), U6.19 (GND), U6.21 (GND), U6.22 (GND), U6.23 (GND), U6.26 (GND), U6.27 (GND), U6.28 (GND), U6.29 (GND), U6.30 (GND), U6.33 (GND), U6.35 (GND), U6.37 (GND), U6.38 (GND), U6.40 (GND), U6.41 (GND), U6.42 (GND), U6.43 (GND), U6.44 (GND), U6.47 (GND), U6.48 (GND), U6.49 (GND), U6.50 (GND), U6.51 (GND), U6.54 (GND), U6.56 (GND), U6.57 (GND)
unnamed: C1.1, C2.1, L1.1, R6.2
unnamed: D1.2 (A), R4.1
unnamed: D2.1 (K), D3.1 (K), JP11.1 (A)
unnamed: D5.1 (K), R7.2
unnamed: D6.2 (A), R5.1
unnamed: F1.2, J1.VBUS
unnamed: J1.A5 (CC1), R2.2
unnamed: J1.B5 (CC2), R1.2
unnamed: J1.S (SHIELD), JP7.2 (B)
unnamed: JP2.1 (A), R4.2
unnamed: JP3.1 (A), R5.2
unnamed: JP9.1 (A), U4.2 (TXD)
unnamed: JP9.2 (B), R3.2
unnamed: JP10.1 (A), U4.3 (RXD)
unnamed: J1.A7 (D-), J1.B7 (D-), U1.1 (I/O1), U1.6 (I/O4), U4.6 (UD-)
unnamed: J1.A6 (D+), J1.B6 (D+), U1.3 (I/O2), U1.4 (I/O3), U4.5 (UD+)
unnamed: C10.2, U4.4 (V3)
PPS: J5.2, JP3.2 (B), U6.20 (TIMEPULSE)
RXD: J2.3, R3.1, U6.9 (RXD)
TXD: J2.2, JP10.2 (B), U6.10 (TXD)
VBUS: D2.2 (A), F1.1, U1.5 (VCC)
VCC_RF: R6.1, U6.31 (VCC_RF)
VDD: C7.1, C14.1, JP11.2 (B), R12.2, U3.1 (VIN), U4.16 (VCC)
V_BCKP: BT1.+, C9.1, R7.1, U6.55 (V_BCKP)
~RESET: J5.3, U6.16 (~RESET)
~SAFEBOOT: J5.1, U6.18 (~SAFEBOOT)

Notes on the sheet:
Close jumper to enable external antenna connection
R3 prevents contention with external connection
Microstrip (Coplanar Single Ended) 50Ω Calculation: https://jlcpcb.com/pcb-impedance-calculator Board thickness: 1.6mm Layers: 4 Er: 4.4 (7628 Prepreg) Dielectric Thickness (Layer 1 to 2): 8.28mil/0.2104mm (JLC7628) Copper Thickness (1oz outer / 0.5oz inner): 1.38mil/0.035mm Polygon Isolation: 7mil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
USB Track Impedance: Coplanar Differential Pair @ 90Ω https://jlcpcb.com/pcb-impedance-calculator Board Thickness: 1.6mm Layers: 4 Er: 4.4 (7628 Prepreg) Dielectric Thickness (Layer 1 to 2): 8.28mil/0.21mm (JLC7628) Copper Thickness (1oz outer / 0.5oz inner): 1.38mil/0.035mm Polygon Isolation: 7mil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
RF Connector
BlueSMiRF Connector
LEDs
DAN-F10N Dualband L1/L5 GNSS Receiver
USB to Serial
Battery Backup
Power
PTH Connectors

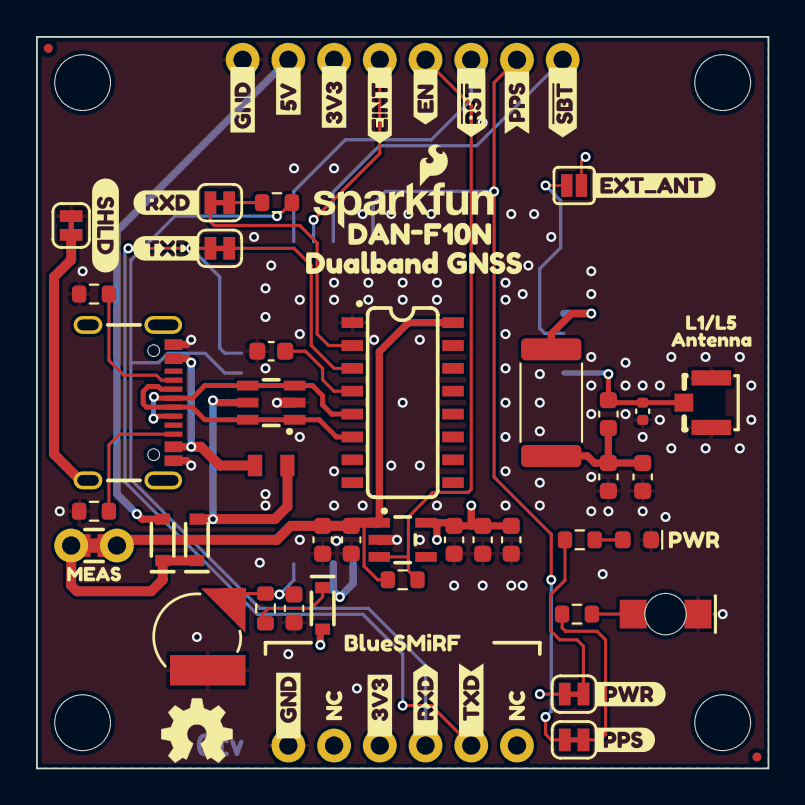
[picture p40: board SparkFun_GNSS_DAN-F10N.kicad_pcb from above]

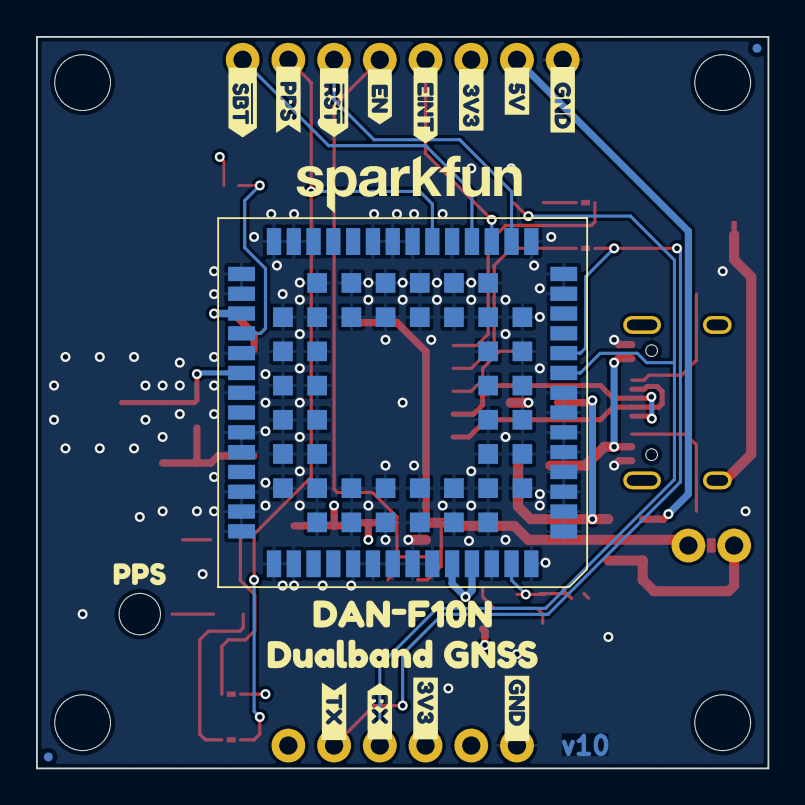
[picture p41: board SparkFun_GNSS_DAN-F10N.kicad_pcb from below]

Board: 4 copper layers, 40.6 x 40.6 mm, 93 parts (18 on the bottom side), 33 nets.

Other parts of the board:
Ref**: Val**; OSHW_Logo_4mm
kibuzzard-64C2E6A3: G***; kibuzzard-64C2E6A3
kibuzzard-64C3DF93: G***; kibuzzard-64C3DF93
kibuzzard-67C7D06A: G***; kibuzzard-67C7D06A
kibuzzard-67C7D061: G***; kibuzzard-67C7D061
kibuzzard-67C52A06: G***; kibuzzard-67C52A06
kibuzzard-67C52AED: G***; kibuzzard-67C52AED
kibuzzard-67C52B01: G***; kibuzzard-67C52B01
kibuzzard-67C52B1C: G***; kibuzzard-67C52B1C
kibuzzard-67C52C8F: G***; kibuzzard-67C52C8F
kibuzzard-67C52CCE: G***; kibuzzard-67C52CCE
kibuzzard-67C52D79: G***; kibuzzard-67C52D79
kibuzzard-67C52D85: G***; kibuzzard-67C52D85
kibuzzard-67C52DD7: G***; kibuzzard-67C52DD7
kibuzzard-67C52DE1: G***; kibuzzard-67C52DE1
kibuzzard-67C52F63: G***; kibuzzard-67C52F63
kibuzzard-67C524B9: G***; kibuzzard-67C524B9
kibuzzard-67C524C4: G***; kibuzzard-67C524C4
kibuzzard-67C526AF: G***; kibuzzard-67C526AF
kibuzzard-67C526C1: G***; kibuzzard-67C526C1
kibuzzard-67C526DE: G***; kibuzzard-67C526DE
kibuzzard-67C526ED: G***; kibuzzard-67C526ED
kibuzzard-67C526F3: G***; kibuzzard-67C526F3
kibuzzard-67C526FD: G***; kibuzzard-67C526FD
kibuzzard-67C527CA: G***; kibuzzard-67C527CA
kibuzzard-67C529FB: G***; kibuzzard-67C529FB
kibuzzard-67C5273C: G***; kibuzzard-67C5273C
kibuzzard-67C5274E: G***; kibuzzard-67C5274E
kibuzzard-67C5275D: G***; kibuzzard-67C5275D
kibuzzard-67C5279A: G***; kibuzzard-67C5279A
kibuzzard-67C52692: G***; kibuzzard-67C52692
kibuzzard-67C52701: G***; kibuzzard-67C52701
kibuzzard-67C52734: G***; kibuzzard-67C52734
kibuzzard-67C52738: G***; kibuzzard-67C52738
kibuzzard-67C52789: G***; kibuzzard-67C52789
kibuzzard-67D33FB6, kibuzzard-67D33FB6#2: G***; kibuzzard-67D33FB6
kibuzzard-67D358AB: G***; kibuzzard-67D358AB
kibuzzard-67D3586F: G***; kibuzzard-67D3586F
kibuzzard-67D3589A: G***; kibuzzard-67D3589A
kibuzzard-67D35894: G***; kibuzzard-67D35894
kibuzzard-67EB0CBA: G***; kibuzzard-67EB0CBA
kibuzzard-6501FDDA: G***; kibuzzard-6501FDDA

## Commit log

2025-03-13 Add ignore
    [SparkFun_GNSS_DAN-F10N.kicad_pcb, SparkFun_GNSS_DAN-F10N.kicad_sch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]
2025-03-31 Fix DAN-F10N footprint. Move EXT_ANT to jumper.
    [SparkFun_GNSS_DAN-F10N.kicad_pcb, SparkFun_GNSS_DAN-F10N.kicad_sch]
2025-04-03 Fix standoff location. Update to v9.
    [SparkFun_GNSS_DAN-F10N.kicad_pcb, SparkFun_GNSS_DAN-F10N.kicad_sch]
2025-04-15 Reduce paste on signal pads. Correct EXT_ANT activation level.
    [SparkFun_GNSS_DAN-F10N.kicad_pcb, SparkFun_GNSS_DAN-F10N.kicad_sch]
2025-04-15 Add panel
    [SparkFun_GNSS_DAN-F10N.kicad_pcb, SparkFun_GNSS_DAN-F10N.kicad_sch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]
2025-04-16 Update PCB details
    [SparkFun_GNSS_DAN-F10N.kicad_pcb]
2025-09-04 Initial Docs Commit
    [cad_model.step]
2025-09-12 Remove local FP/SYM. Update to main kicad library.
    [DAN-F10N_AntennaModule.STEP, SparkFun_GNSS_DAN-F10N.kicad_pcb, SparkFun_GNSS_DAN-F10N.kicad_sch]
2025-09-17 Update KiCAD files
    Updates footprint position for 3D model
    [SparkFun_GNSS_DAN-F10N.kicad_pcb]

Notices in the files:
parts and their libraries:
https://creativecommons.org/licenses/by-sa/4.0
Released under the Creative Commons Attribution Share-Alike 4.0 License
